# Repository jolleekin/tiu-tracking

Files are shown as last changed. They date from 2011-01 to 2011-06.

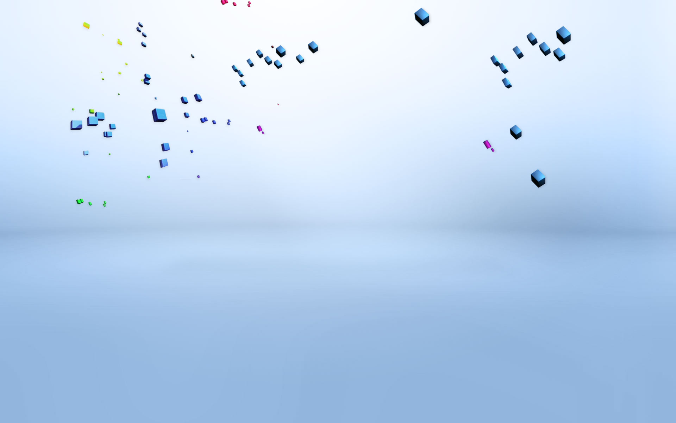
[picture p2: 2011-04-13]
Software/WebApp/images/bg_cubes.jpg

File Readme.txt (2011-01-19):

TIUTRACKING - RFM12's TxRx v.1 -------------------------------------------------------
Demo package for our capstone project -  TIU Tracking (PSU, Intel) - version 1.0
by Dung Dang Le - Email: zung.dang.le at gmail.com

This package demonstrates wireless communication on hobby frequency 
band (i.e 433MHz...) using RFM12B transceiver modules and ATMega328 uC.
Our purpose is testing these RFM12B module functions: transmit/receive/Analog-RSSI,
which could be considered applying for our project later.

There are two different approaches will be introduced:
    + polling, no checksum based on Benedikt's library
	+ interrupt with checksum based on RF12 arduino library by Jeelabs 
	
Notes: 
 - No collision avoidance is considered yet in this version
 - To get ARSSI output, you may have to manually solder on a wire to a resistor to 
   access this pad (see picture on schematic folder, location shown in red circle).
   (thanks to Stephen Eaton)
 - Schematic provided by Jeelabs, used for both transmiting receiving modules
 - Antennas required for best performance, Ideally at 433MHz ~ 17cm length
 - Yeah, I used arduino board to program the chips and monitor the serial outputs
 ------------------------------------------------------------------------------------

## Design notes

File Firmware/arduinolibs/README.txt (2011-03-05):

DDL: PUT THESE LIBRARIES IN ARDUINO LIBRARY FOLDER.

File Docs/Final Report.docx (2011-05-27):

# Abstract

TIU tracking system is a capstone project conducted by Portland State University students and sponsored by Intel Corp. The system will be used to track locations of Test Interface Units (TIUs) in the Intel Validation Lab.

In this paper, we propose a general architecture for the tracking system. The main goal of the architecture aims to achieve a low-cost, yet effective tracking system. The infrastructure of the tracking system is built upon RF transceivers which communicate wirelessly in a mesh network. The asset tags will be attached to tracked devices (TIUs). These asset tags will broadcast messages to detectors. Messages that contain received signal strength indication (RSSI) values will be routed though the mesh network to a server. The server will analyze the received data, calculate the locations, and store them in the database. A web application will then be able to access the database and display location information in an interactive 2D map.

The primary figures of merit that were used in the decision making process include accuracy, power consumption, size, and cost. The last administrative idiom this paper conveys is a road map which will guide our team to the final objective. The means by which this is accomplished is through a tentative schedule, timeline, a list of milestones and expected deliverables.

# 1 Introduction

Location aware computing has a bright future in the fields of personal navigation, personal security, prompt healthcare and entertainment. Furthermore, information on the physical location of mobile nodes can greatly help in urban search and rescue missions, as well as enable geographical routing in ad hoc multi-hop networks. The determination of physical location is sometimes referred to as location estimation, location identification, localization, and positioning or geolocation identification.

Chip manufacturers today face dramatic upheaval across the industry. Companies (such as Intel) need to find ways to remain profitable at a time when economic turbulence is curtailing consumer buying power. In the midst of these changes, plant managers must find a way to address the problem of improving processes while becoming more cost-effective.

As part of this effort, Intel wants to automate tracking of the Test Interface Units (TIU) at different locations of the Intel lab, with the intention of wirelessly locating a TIU’s physical position at all times. Given the size and complexity of Intel validation lab, locating Test Interface Units (TIU) can be a tedious task since the test equipments have to be broken down to identify the TIU it is using. Therefore, an effective TIU tracking system rises as an urgent need.

By tracking location of the TIU’s physical position in the lab, Intel can minimize downtime and decrease labor costs caused by the size and complexity of Intel validation lab. This solution enables:

- Increased equipment utilization
- Decreased loss and theft
- Reduced costs
- Faster production
- Avoid time wasted on manual searches and inventory checks.

This capstone project will be a prototype system that can wirelessly track the location of at least 10 TIUs in an indoor environment. The duration of the project will last 6 months.

# 2 Specification

## 2.1 System Overview

Figure 3-1 shows a network of detectors that are geometrically located in a grid array. The density of the grid array will primarily be a ratio of accuracy and cost. For the scope of this project, the reasonable number of detectors would be from five to seven. The location of the proxy must be within range of at least one detector.

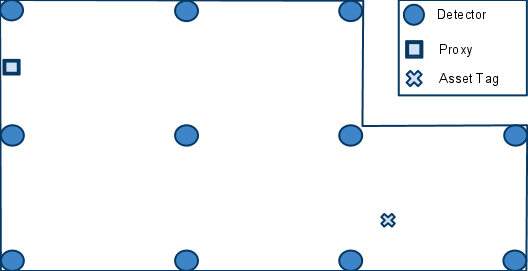
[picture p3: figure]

Figure 1: A hypothetical room with detectors positioned in a grid array. Also shown is an arbitrarily placed proxy.

There are two distinct networks which compose this system: the front-end network, which includes all the physical nodes, and the back-end network, which includes all the logical nodes (Figure 3-2). The proxy is the gateway between the two networks.

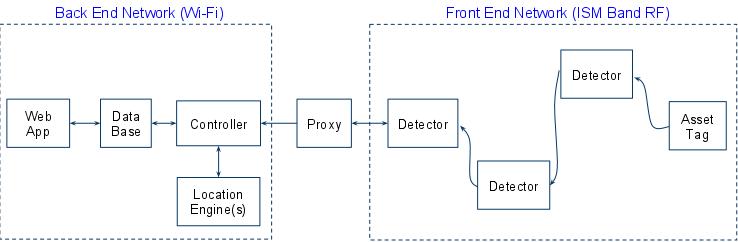
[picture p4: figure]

Figure 2: Front-end and back-end network topologies.

There are three important aspects to the communications that take place in the front-end network.

- Each asset tag will broadcast a message periodically. Neighboring detectors will detect the broadcast, and determine the RSSI of the broadcasting asset tag.
- When a detector determines the RSSI of a broadcasting asset tag, it must then transmit this data towards the proxy using a routing table. The routing table will be configured in such a way as to ensure the data moves in a direction that is physically towards the proxy.
- The locating application will periodically receive bursts of RSSI information from various detectors. Since it has no knowledge of how many detectors actually detected a broadcasting asset tag, it will wait a certain amount of time that assumes all the RSSI information from the various detectors has finished coming in.

Now we will further discuss some finer points of the second aspect. Figure 3-3 shows the paths taken as a result of an asset tag’s broadcasting. When an asset tag broadcasts, the nearest detectors are able to determine the corresponding RSSI values. The detectors that detected the asset tag broadcast are denoted by a connection with a green arrow. Each detector will have a routing table programmed into them. The routing table will contain information that steers the messages physically toward the proxy. In the example shown in Figure 3-3, the routes taken are in red. The blue dash paths are routes that exist but are not taken.

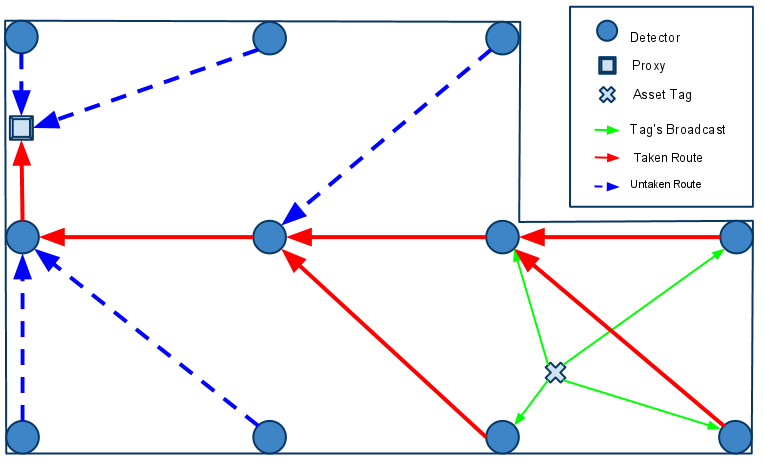
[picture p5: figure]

Figure 3: An example of the routing paths as a result of an asset tag’s broadcasting.

## 2.2 Software

### 2.2.1 Front-end Software

The front-end software consists of the firmware for the detectors, and the asset tags.

For a detector to determine the RSSI of an asset tag, the asset tag must broadcast a message. The message has six fields, as shown in Figure 3-4. The way the fields are used depends on the origin of the message. There are two possible origins of a message. The first type of origin is an asset tag. A message can be identified as coming from an asset tag by examining the DID, SID, and RSSI value fields. If all three fields contain the value zero, then the message originates from an asset tag. Otherwise, the message originates from a detector.

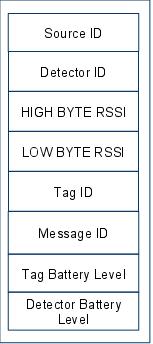
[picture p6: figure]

Figure 4: Message format.

When receiving a message whose DID is not zero, a detector will do four things:

1. Replace the DID of the message with a DID contained in its routing table
2. Replace the SID of the message with its own ID
3. Replace the RSSI value with that inferred from the reception of the asset tag broadcast
4. Rebroadcast the message

An example of this message passing sequence is show in Figure 5. (Need modified)

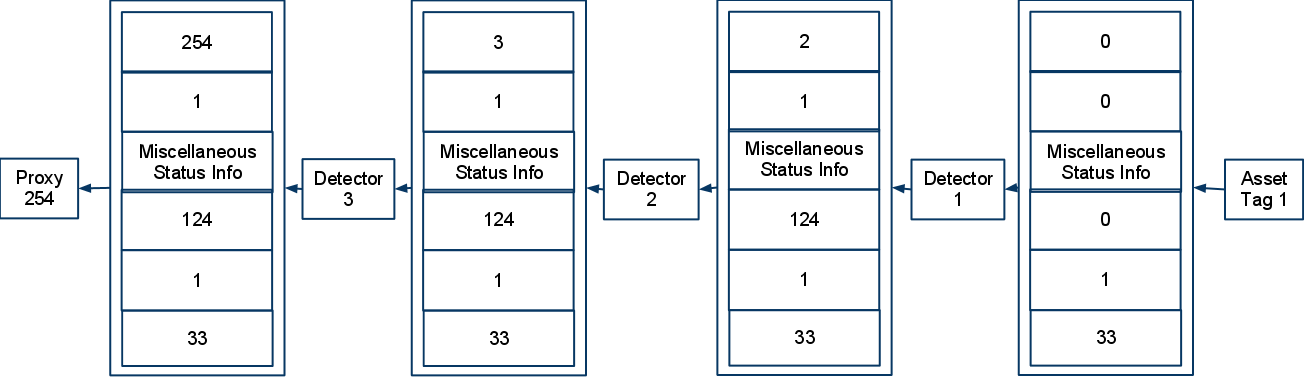
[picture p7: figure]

Figure 5: A example of a message originating from a asset tag, and being relayed to a proxy.

### 2.2.2 Back-end Software

The back-end network, composed exclusively of logical nodes, will rely on normal internet communication. This allows applications to leverage TCP/IP and many APIs that have been built upon it. Also, we gain the advantage of being able to have standard inter-nodal communication regardless of if they exist on the same computer or not. This increases the scalability of the system.

The back-end software system consists of four components:

- SQL Database
- Web Application
- Controller
- Location Engine

#### 2.2.2.1 SQL Database

The SQL database is a central component that provides a link among the web application, the controller, and the location engine. Specifically, the database stores the following data:

- Location update interval
- Geometry of the tracking area
- RSSI-distance model or RF fingerprinting
- Identifications and locations of the detectors
- Identifications, locations, and battery levels of the TIUs
- Mapping table between asset tags’ ID and TIUs’ ID

We agree on using SQL since it is a standard that is easy to use, secure and scalable.

#### 2.2.2.2 Web application

The web application provides an interface for users to access the location information in the database. Its functionalities are:

- Display the locations and battery levels of all tracked TIUs on an interactive 2D map
- Allow users to search for a TIU via its ID. In case the ID is not complete or unique, the application will highlight the locations of all matched TIUs
- Allow users to view location history of the TIUs
- Alert users when a TIU is brought out of bounds or when it runs out of battery

The web application consists of two components: the client side and the server side. The client side will be implemented using modern web technologies such as HTML5, JavaScript, CSS3, and AJAX. The server side could be built upon one of the two most popular web server applications, i.e. Microsoft IIS and Apache.

#### 2.2.2.3 Controller

The controller application is a GUI application that allows an administrator to manage the system. It allows the administrator to

- Modify the geometry of the tracking area
- Remap asset tags’ ID to TIUs’ ID
- Add or remove devices (detectors and asset tags)

The controller also receives RSSI data from the proxy, preprocesses them before feeding them into the location engine.

#### 2.2.2.4 Location Engine

The location engine receives RSSI values from the controller and uses those values to calculate the locations of the asset tags. The derived locations will then be stored in the database.
In case of using battery to power the asset tags, this application also receives battery level reports of the asset tags from the detectors and update the data in the database. This application should be written in a programming language that supports SQL database access and network communication.

The controller and the locating applications are discussed herein as two separate applications. However, they can definitely be combined into one single application.

## 2.3 Hardware

### 2.3.1 Tag

An asset tag consists of two major parts:

- Microcontroller: ATMega328P – 32 TQFP
- RF transceiver: RFM12B-S2 Wireless Transceiver Module

Table 1: Tag Specifications

Specification | Description
Microcontroller | ATMega328P – 32 TQFP
RF Transceiver | RFM12B-S2 Wireless Transceiver
Voltage regulator | XC6221
Power supply | 6V Battery (two 3-V coin cells in holder)
Program Interface | ISP 6-pin header
Operating Frequency Band | ISM 433 MHz
Power Indicator | No
RF Indicator | No
PCB size
Microcontroller module | 25.4mm x 25.4mm
RF Transceiver | 20.3mm x 25.4mm
Outline Dimension

Table 2: Electrical Characteristics

Specification | Min | Typ | Max | Unit
Power Supply | 3.3 | 6.0 | 6.0 | V
Transmit Current
Receive Current
Idle Current
Power-down Current
Power Dissipation
Operating Temperature | -25 | | +85 | ⁰C

The microcontroller controls the RF transceiver. The RF transceiver is responsible for communicating information to the system.

Figure 6: Board layout of the controller module on a tag

Figure 7: Board layout of the RF module on a tag

### 2.3.2 Detector

A detector consists of two major parts:

- Microcontroller: ATMega328P – 28 DIP
- RF transceiver: RFM12B-S2 Wireless Transceiver

Table 3: Detector Specifications

Specification | Description
Microcontroller | ATMega328P – 28 DIP
RF Transceiver | RFM12B-S2 Wireless Transceiver
Voltage regulator | MIC5205 150mA Low-Noise LDO Regulator
Power supply | 9V Battery
Program Interface | ISP 6-pin header
Operating Frequency Band | ISM 433 MHz
Power Indicator | Yes (regular red LED)
RF Indicator | Yes (green LED)
PCB size | 25.4mm x 88.9mm
Outline Dimension

Table 4: Electrical Characteristics

Specification | Min | Typ | Max | Unit
Power Supply | 3.3 | 9.0 | 16.0 | V
Transmit Current
Receive Current
Idle Current
Power-down Current
Power Dissipation
Operating Temperature | -25 | | +85 | ⁰C

Figure 8: Board layout of a detector

The microcontroller controls the RF transceiver. The RF transceiver is responsible for communicating information to the system.

### 2.3.3 Proxy

The proxy consists of three major parts:

- Microcontroller unit
- RF transceiver unit: RFM12B-S2 Wireless Transceiver Module
- Wi-Fi transceiver: WiFly GSX Module

Table 5: Proxy Specifications

Specification | Description
Microcontroller | ATMega328P – 28 DIP
RF Transceiver | RFM12B-S2 Wireless Transceiver
Voltage regulator | LM317
Power supply | 6V Battery
Program Interface | USB
Operating Frequency Band
RF Transceiver | ISM 433 MHz
Wi-Fi Transceiver | 2.4 GHz Standard
Power Indicator | Yes
Transmission Indicator | Yes
Outline Dimension | Prototype on bread board

Table 6: Electrical Characteristics

Specification | Min | Typ | Max | Unit
Power Supply | 3.3 | 6V | 6V | V
Transmit Current
Receive Current
Idle Current
Power-down Current
Power Dissipation
Operating Temperature | -25 | | +85 | ⁰C

The microcontroller is responsible for relay data between the two transceivers.

### 2.3.4 Parts Selection

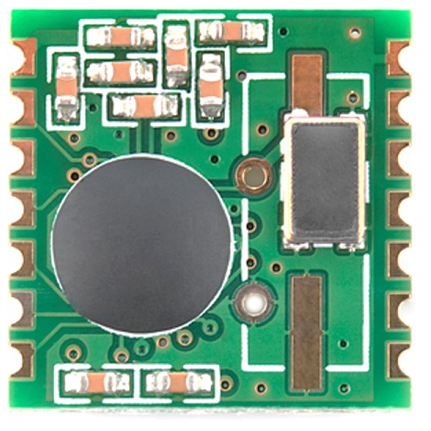
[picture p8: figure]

Figure 9: RFM12B-S2 Wireless Transceiver Module

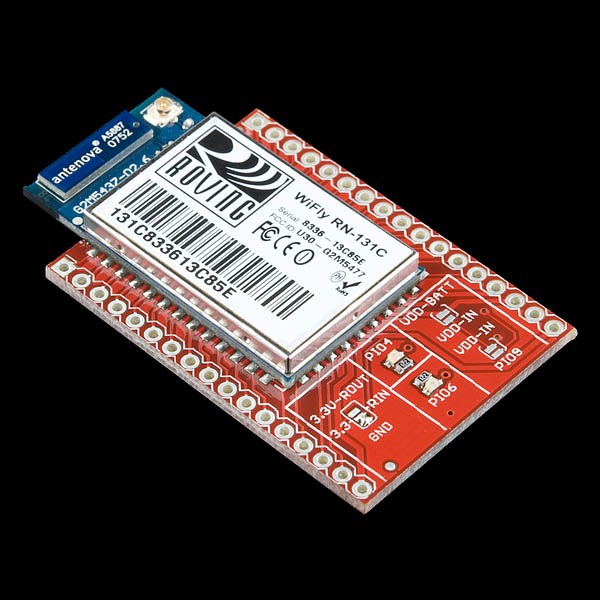
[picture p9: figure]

Figure 10: WiFly GSX Breakout

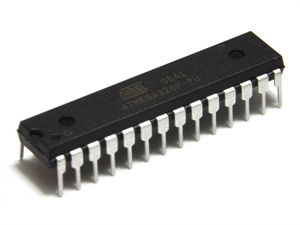
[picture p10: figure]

Figure 11: ATMega328P – 28 DIP Pinout

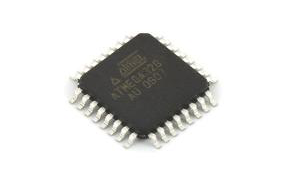
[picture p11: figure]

Figure 12: ATMega32P – 32 TQFP Pinout

Refer to datasheets provided by manufacturers for more information (See Useful Links section in Appendices).

# 3 Test Plan

## 3.1 Unit Tests

## 3.2 Hardware

### 3.2.1 Power supply unit

### 3.2.2 Tag

### 3.2.3 Detector

### 3.2.4 Proxy

## 3.3 Software

### 3.3.1 Controller

### 3.3.2 Web App

### 3.3.3 Database

## 3.4 System Tests

### 3.4.1 Test case 1:

1 Tag, 1 Detector, Serial

### 3.4.2 Test Case 2:

1 Tag, 1 Detector, Proxy

### 3.4.3 Test Case 3:

1 Tag, Multiple Detectors

### 3.4.4 Test Case 4:

Multiple Tags, Multiple Detectors, Proxy, Database

## 3.5 Acceptance Tests

### 3.5.1 Test case 1:

10 Tags, 8 Detectors, Proxy, Controller, Web App

Accuracy Requirement Met?

Power Requirement Met?

Update Interval Requirement Met?

## 3.6 Final Results

### 3.6.1 Device dimensions

### 3.6.2 Power consumption

### 3.6.3 Accuracy

# 4 Conclusions

## 4.1 What we learned

## 4.2 Good Decisions

## 4.3 Bad Decisions

## 4.4 Meeting our Expectations

## 4.5 Meeting our Sponsors Expectations

## 4.6 Group Dynamics

# 5 Appendices

## 5.1 Installation

### 5.1.1 Detector Deployment

### 5.1.2 Tag Deployment

### 5.1.3 Controller Setup

### 5.1.4 Proxy Setup

## 5.2 Maintenance

### 5.2.1 Replacing Batteries

## 5.3 User Guide

### 5.3.1 Web-based application

### 5.3.2 Controller application

## 5.4 Useful Links

# 6 References

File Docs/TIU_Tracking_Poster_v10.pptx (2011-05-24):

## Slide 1

TIU Tracking System

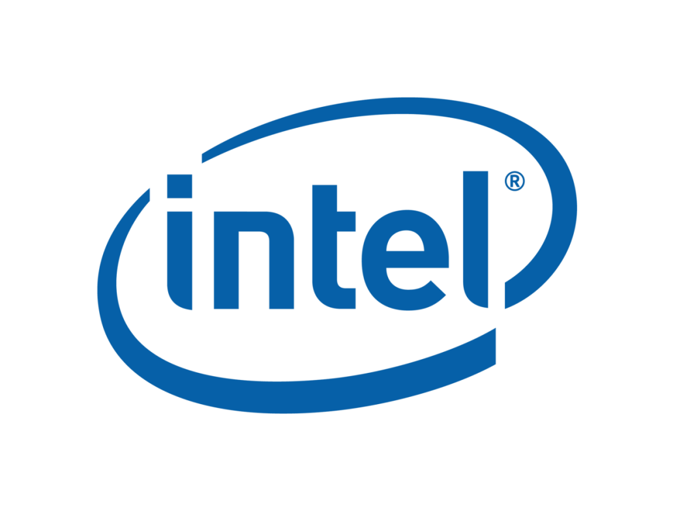
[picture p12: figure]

Capstone 2011
Sponsored by Intel
Advisor: Prof. Robert Daasch

Team Members:
Daniel Ferguson – Dung Le
Lynh Pham – Man Hoang – Tri Truong

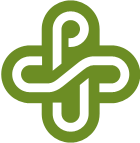
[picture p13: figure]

Introduction

Intel's large and complex validation labs contain many Test Interface Units (TIUs) used in validating hardware. A TIU is a custom PCB that provides test points that a testing machine can probe. Since the hardware to be tested is varied, there exists a variety of different TIU's, and as such, finding a particular TIU is useful because, previously, the testing machine had to be broken down to identify the TIU it was using.

Approach

The system uses an RF transceiver mesh network to track mobile tags indoors. The system determines a tag’s current location by matching the RF signal strength pattern of a tag’s periodic broadcast with pre-collected patterns stored in a database.
Radio Received Signal Strength Indication (RSSI) is a measurement of the power received by an antenna. Signal strength based location method has several advantages over other methods such as GPS, IR, and Acoustics as it is easy to implement and does not require line of sight. Also, low cost RF transceivers are readily available.
For scalability, a mesh network of detectors relay all data to a centralized controller where locations of the tags are calculated and saved in a database. An easy to use web application provides visualization of tag locations, as well as other configuration details.

Design

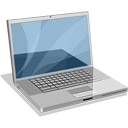
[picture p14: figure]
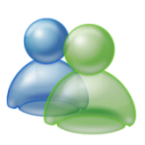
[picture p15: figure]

Users

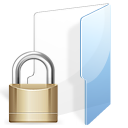
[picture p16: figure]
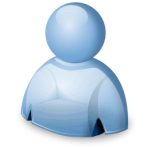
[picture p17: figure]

Admin

Back-end

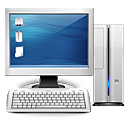
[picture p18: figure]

Web App

Controller

Front-end

Wi-Fi

Database

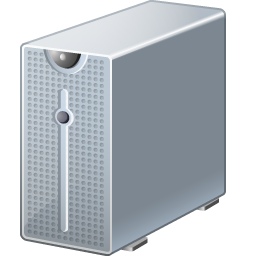
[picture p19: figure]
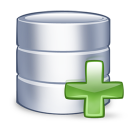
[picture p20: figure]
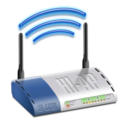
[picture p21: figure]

Proxy

Detector

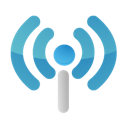
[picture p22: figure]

Tag

Products

Asset Tag
- Size: 1”x1”x1”
- ATMega328p MCU
- RF12B transceiver at 434MHz
- 20mm coin cell battery
- Battery life: at least 1 months
- Cost : $25

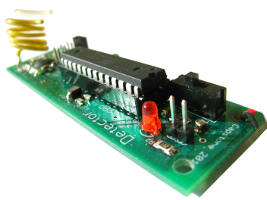
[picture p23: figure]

Detector
- Size: 3.5”x1”
- ATMega328p MCU
- RF12B transceiver at 434MHz
- 9V battery/adapter
- Cost: $30

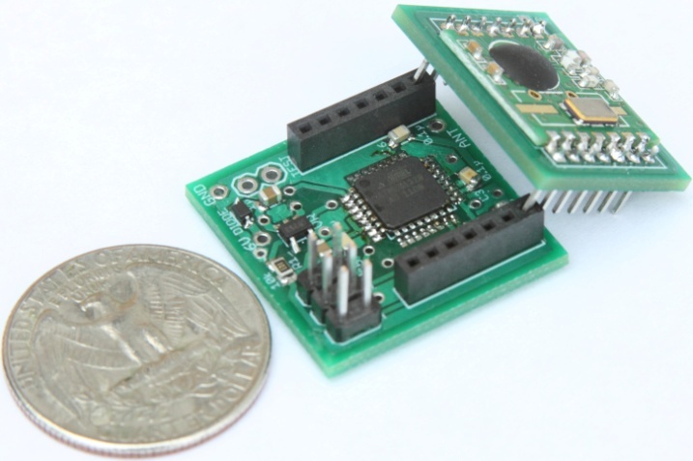
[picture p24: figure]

Controller
- Receives RSSI and battery data from the mesh network
- Executes the locating algorithm
- Communicates with the Database
Fingerprint Algorithm
- A pattern matching algorithm based on Euclidean distance
- Employs heuristics and input/output filters to further enhance the accuracy and reliability of the locating process
where
- d = Euclidean distance
- N = Number of detectors
- RSSIli = RSSI value from detector i in locating phase
- RSSIci = RSSI value from detector i in calibrating phase
Web Application
- Primary user interface with an interactive 2D map
- Search TIUs and detectors via ID
- Display locations and battery levels of all tags and detectors
- Configure tags and detectors
- Configure the tracking area

Tags
- Attached to TIUs
- Periodically broadcast
- When not broadcasting, in a low power state
Detectors
- Listen to messages from tags and determine the RSSI values
- Forward the messages to the proxy via a controlled flooding mechanism
- Implements collision avoidance using time division
Wi-Fi Proxy
- Relays data from the mesh network to the controller
SQL Database
- Stores locations and battery levels of all tags and detectors
- Stores user accounts

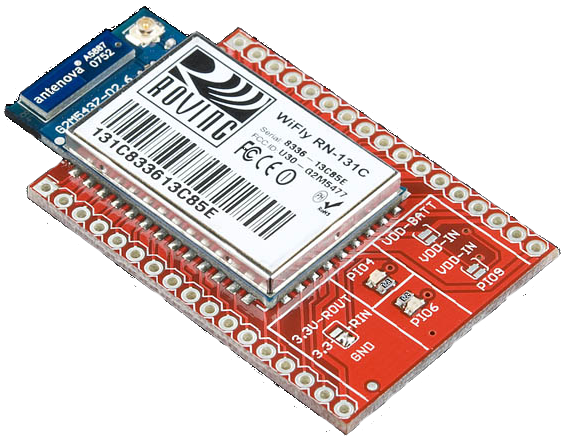
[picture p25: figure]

Proxy
- ATMega328p MCU
- RF12B transceiver at 434MHz
- WiFly 802.11b/g transceiver
- 9V battery/adapter
- Cost: $80

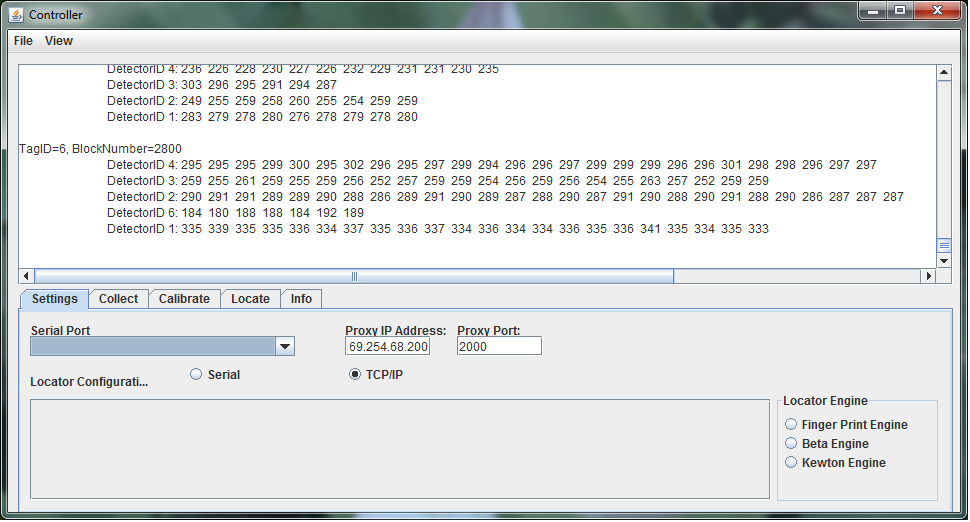
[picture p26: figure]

Experiments


Conclusions

The system has been able to meet three important requirements: small size, low cost, and battery life exceeding one month. As for accuracy, the average value is roughly 2m. The result is much better when the tags are close to the calibration points.
Further work to be done includes
- Refine the testability of the system
- Analyze antenna radiation pattern
- Improve the robustness of the location algorithm

Department of Electrical and Computer Engineering


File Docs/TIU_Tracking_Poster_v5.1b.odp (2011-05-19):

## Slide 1

Requirements

- Asset tag’s size: 1” x 1” x 1”
- Low power consumption
- Accurate
- Web application as user interface
- 2D map display
- Scalable tracking area
- Low cost solution

Introduction

This system uses an RF transceiver network to track mobile assets indoors, where more obvious solutions, such as GPS, are unable to function. A web app is the primary user interface, and is used to query the location of an asset.

Tags, which are placed onto Testing Interface Units(TIUs), periodically broadcast a signal which are picked up by detectors that are placed in various fixed locations within the tracking area. The detectors determine the signal strength of the tags, form a message and relay it, via a mesh network forwarding protocol, until the message reaches the proxy. The proxy then retransmits the message via wifi to the controller. The controller gives the signal strength data to a locating algorithm which calculates its approximate location via statistical analysis. The results are then placed into a database where the web app retrieves the results and displays them on an interactive 2D map.

Design


Proxy


Controller

Detector


Users


Admin

Web App


TIU Tracking System


Capstone 2011

Sponsored by Intel

Advisor: Prof. Robert Daasch

Team Members:

Daniel Ferguson – Dung Le

Lynh Pham – Man Hoang – Tri Truong

Products


Asset Tag

- Size: 1”x1”x1”
- Use ATMega328p MCU
- Use 20mm coin cell battery
- Battery life: more than 3 months
- Use RF12B transceiver at 434MHz

Detector

- Size: 3.5”x1”
- Use ATMega328p MCU
- Use 9V battery/adapter
- Use RF12B transceiver at 434MHz


Features

RF Mesh Network

- Composed of small, inexpensive hardware.
- Relay messages to proxy via a controlled flooding mechanism.
- Collision avoidance using time division
- Tags broadcast periodically
- Detectors pick up broadcast, determine RSSI, and send results.
- Detectors also act as relays.

Wi-Fi Proxy

- RFM12 receives data from mesh network
- Wifi module sends data to the controller.

Fingerprint Algorithm

- A progressively constrained, nearest neighbor algorithm, using euclidean distance as the matching metric. Also, several heuristics are employed that further enhance the accuracy and reliability of the locating process.

Controller

- Primary link between the mesh network and the back end infrastructure.
- Communicates with mesh network
- Executes the locating algorithm
- Communicates with the Database.

Approach

By collecting RF signatures and storing them in a database. The RF signature created by a tag's broadcast can be compared to those stored, and the closest match roughly identifies the location of the tag.

Data originates in the mesh network, and is relayed to controller software that feeds it to a locating algorithm. The locating algorithm calculates the location, gives the results back to the controller, and the controller then places the results into the database.

The locating algorithms implement a standardized interface which facilitates easy integration with the system, and supports the addition of different locating algorithms.

Test Results


Web Application

- Primary user interface.
- Interactive 2D map
- Search TIU and detector via ID
- Show battery level of all elements in the mesh network.
- Configure Detector placement
- Configure geometry of tracking area

SQL Database

- Tag locations
- Battery levels of all transceiver devices

Conclusions

The accuracy of the tracking system needs to be enhanced by considering antenna design and advanced locating algorithm. Noise filter can be implemented on both hardware and software to achieve desired performance.

Database

Department of Electrical and Computer Engineering


Tag


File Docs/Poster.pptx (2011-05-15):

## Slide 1

TIU Tracking System


Capstone 2011

Introduction

This system uses an RF transceiver network to track mobile assets indoors, where more obvious solutions, such as GPS, are unable to function. The system determines an asset’s current location by matching the RF fingerprint of its periodic broadcasts with previously collected fingerprints stored in a database

Requirements
- Asset tag’s size: 1” x 1” x 1”
- Low power consumption
- Accurate
- Web application as user
- interface
- 2D map display
- Scalable tracking area
- Low cost solution

Team
Sponsor: Intel
Advisor: Prof. Robert Daasch
Members: Dung Le
Tri Truong
Lynh Pham
Man Hoang
Daniel Ferguson

Design

Infrastructure
RF Network
Location Algorithm
Fingerprint
User Interface
Web App
Management
Wi-Fi Proxy
Server Computer
Voting Method
Controller
Web App

Results

Conclusions
The tracking system consists of two primary parts: hardware and software. The hardware infrastructure is built upon RF technology. The number of detectors will be scaled in order to achieve the desired accuracy and efficiency.

Asset Tag
- Size: 1”x1”x1”
- Use RF12B transceiver at 434MHz
- Use MCU ATMega328p
- Use coin cell 20mm battery
- Battery life: more than 1 month


Proxy
- Use WiFly 802.11b/g at 2.4GHz
- Use RF12B transceiver at 434MHz
- Use MCU ATMega328p
- Use 9V battery/adaptor

Controller
- ghghghghdgfh
- fggfhgh

Web Application
- User and Admin interface
- Interactive 2D map
- Search TIU and detector via ID
- Show battery level
- Add and remove tag/detector
- Change geometry of tracking area

SQL Database
- RSSI-distance model or RF fingerprinting
- Location update interval
- Geometry of the tracking area
- Identifications, locations, and battery levels of the TIUs


Detector
- Size: 3.5”x1”
- Use RF12B transceiver at
434MHz
- Use MCU ATMega328p
- Use 9V battery/adapter


Admin

Back-end


Internet

Front-end


Users


Detector


Tag

Disadvantages

- Noise sensitive
- Calibration required

Detector


Controller


Proxy


Battery Life

- Capacity of lithium coin cell: 240mAh
- Transmission time: 3ms every 1 seconds
- Active current: 30mA (RF transceiver + MCU)
- Sleep current: 0.0425mA


Accuracy

- Testing ………

Detector


Advantages

- Low cost
- Small size
- Easy scalability
- Low power consumption

Department of Electrical and Computer Engineering

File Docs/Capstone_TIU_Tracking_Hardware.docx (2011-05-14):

# 1 Hardware

The infrastructure of the tracking system consists of detectors, asset tags, proxies and a server, as shown in Figure below


## 1.1 Detectors

A detector consists of two major parts: a microcontroller, and a RF transceiver. The microcontroller controls the RF transceiver. The RF transceiver is responsible for communicating information to the system.

### 1.1.1 Functionality


Figure 1: Detector functionality

Module | Detectors
Inputs | - Power supply: 3.3V DC - Messages from asset tags and other detectors
Outputs | - Messages from asset tags and other detectors
Functionality | A detector consists of two major parts: a microcontroller, and a RF transceiver. The microcontroller controls the RF transceiver. The RF transceiver is responsible for communicating information to the system.

### 1.1.2 What is on the board

- A power switch on/off
- A 3.3V power regulator which accepts up to 16V as external power source.
- An ATMega328p MCU by Atmel with 8MHz
- A 6pins SPI connector for programming.
- A RFM12B wireless RF module for 434MHz ISM band by Hope RF.
- A LED with jumper (on/off) for checking power.
- A LED with jumper (on/off) for checking signal transmission.

### 1.1.3 Advantage

- By including a 3.3V regulator, the detector can be powered a DC power adapter, or various types of 3.6 … 16V batteries.
- The RFM12B module is a low cost option with sufficient power and range to provide reliable communication around the lab - a basic packet protocol can be implemented in just 2..3 Kb of C code.
- Had 2 LEDs for debugging power and signal transmission.
- Small size 1” x 3.5”.
- There are many possible microcontrollers we could use to implement a solution. The ATmega 328p is a good choice because they are the Arduino technology platform.
- FR12B transceiver is a good choice because of low price, good support and low power consumption.

### 1.1.4 Schematic


## 1.2 Board layout


## 1.3 Real Board


### 1.3.1 Port/Pin Mapping

#### 1.3.1.1 ATMage328p – 28pins


Pin | Name | Description
1 | PC6 | RESET/PCINT14
2 | PD0 | PCINT16/RXD
3 | PD1 | PCINT17/TXD
4 | PD2 | PCINT18/INT0
5 | PD3 | PCINT19/OC2B/INT1
6 | PD4 | PCINT20/XCK/T0
7 | VCC | VCC
8 | GND | GROUND
9 | PB6 | PCINT6/XTAL1/TOSC1
10 | PB7 | PCINT7/XTAL2/TOSC2
11 | PD5 | PCINT21/OC0B/T1
12 | PD6 | PCINT22/OC0A/AIN0
13 | PD7 | PCINT23/AIN1
14 | PB0 | PCINT0/CLKO/ICP1
15 | PB1 | OC1A/PCINT1
16 | PB2 | SS/OC1B/PCINT2
17 | PB3 | MOSI/OC2A/PCINT3
18 | PB4 | MISO/PCINT4
19 | PB5 | SCK/PCINT5
20 | AVCC | AVCC
21 | AREF | AREF
23 | GND | GROUND
23 | PC0 | ADC0/PCINT8
24 | PC1 | ADC1/PCINT9
25 | PC2 | ADC2/PCINT10
26 | PC3 | ADC3/PCINT11
27 | PC4 | ADC4/SDA/PCINT12
28 | PC5 | ADC5/SCL/PCINT13

#### 1.3.1.2 SPI connector


Pin | Name | Description
1 | MISO | master in / slave out
2 | +5V | Regulated +5V
3 | SCK | SPI clock
4 | MOSI | master out / slave in
5 | RESET | Reset
6 | GND | ground

#### 1.3.1.3 RFM12B


Pin | Name | Description
1 | SDO | Serial data output
2 | nIRQ | Interrupts request output
3 | FSK/DATA/nFFS | Transmit FSK data input/Received data output/FIFO select
4 | DCLK/CFIL/FFIT | Clock output/Extrenal filter capacitor/FIFO interrupts
5 | CLK | Clock output for external microcontroller
6 | nRES | Reset output
7 | GND | Ground
8 | ANT | Antenna
9 | VDD | VCC
10 | GND | Ground
11 | nINT/VDI | Interrupt input
12 | SDI | SPI data input
13 | SCK | SPI clock input
14 | nSEL | Chip select

### 1.3.2 Part list

Part | Value | Details
ATMega328 | Atmel's ATMega328 | Atmel's ATMega328 8-Bit Processor in 28 pin DIP
RFN12B | RFM12B-S2 | RFM12B-S2 Wireless Transceiver
Socket IC | Socket for ATMega328p | Socket IC open frame 28Pos 0.3”
SPI | SPI 6 pins connector | 6 POS connector header
PWR_SW | Power switch | SPDT Mini Power Switch
VR | Voltage regulator 3.3V | IC VREG LDO 3.3V
DIODE | Diode | DIODE SBR 1A 30V SOD-323
C1, C1 | 1uF | CAP CERM 1UF 25V Y5V 0805
C3, C4, C5, C6 | 0.4uF | CAP CERM .10UF 50V 5% 0805 SMD
L1 | 10uH | INDUCTOR 10UH 10% SA TYPE SMD
R1 | 10K | RES 10K OHM 1/4W 5% 0805 SMD
PWR_LED | Power LED 3mm | Power LED 3mm
RF_LED | LED 3mm | LED for signal transmission
JP_RF_LED | 2 pins male header | 2 pins male header
JP_PWR_LED | 2 pins male header | 2 pins male header

## 1.4 Asset Tags

An asset tag consists of two major parts: a microcontroller, and a RF transceiver. The microcontroller controls the RF transceiver. The RF transceiver is responsible for communicating information to the system.

### 1.4.1 Functionality


Figure 2: Asset tag functionality

Module | Asset Tags
Inputs | Power supply: 3.3V DC
Outputs | Messages containing tag’s ID
Functionality | An asset tag consists of two major parts: a microcontroller, and a RF transceiver. The microcontroller controls the RF transceiver. The RF transceiver is responsible for communicating information to the system.

### 1.4.2 What is on the board

- A power switch on/off
- A 3.3V power regulator which accepts 2.2V to 6V as external power source.
- An ATMega328p MCU by Atmel with 8MHz
- A 6pins SPI connector for programming.
- A RFM12B wireless RF module for 434MHz ISM band by Hope RF.
- A jumper which connect to DP3 pin of ATMega328p for debug/mode.
- 2x7pins headers female for connecting with RFM12B breakout board.

### 1.4.3 Advantage

- Designed from the ground up to support very low-power use with batteries.
- The RFM12B module is a low cost option with sufficient power and range to provide reliable communication around the lab - a basic packet protocol can be implemented in just 2..3 Kb of C code.
- Very small size 1” x 1”
- Very low power consumption
- There are many possible microcontrollers we could use to implement a solution. The ATmega 328p surface mount packet is a good choice because they are the Arduino technology platform and very small size.
- FR12B transceiver is a good choice because of low price, good support and low power consumption

### 1.4.4 Battery life

- Capacity of coin cell: 240mAh
- Transmission time: 3ms every 1 seconds
- Active current: 30mA (RF transceiver + MCU)
- Sleep current: 0.0425mA

Then, the approximate battery life is

Battery Life=(240mAh)/(30.0425mA×(3ms)/(1s))=2662.89hr≈110.95days

### 1.4.5 Schematic


### 1.4.6 Board Layout


### 1.4.7 Real Board


### 1.4.8 Port/Pin Mapping

#### 1.4.8.1 ATMage328p – 32pins


Pin | Name | Description
1 | PD3 | PCINT19/OC2B/INT1
2 | PD4 | PCINT20/XCK/T0
3 | GND | GROUND
4 | VCC | VCC
5 | GND | GROUND
6 | VCC | VCC
7 | PB6 | PCINT6/XTAL1/TOSC1
8 | PB7 | PCINT7/XTAL2/TOSC2
9 | PD5 | PCINT21/OC0B/T1
10 | PD6 | PCINT22/OC0A/AIN0
11 | PD7 | PCINT23/AIN1
12 | PB0 | PCINT0/CLKO/ICP1
13 | PB1 | OC1A/PCINT1
14 | PB2 | SS/OC1B/PCINT2
15 | PB4 | MOSI/OC2A/PCINT3
16 | PB4 | MISO/PCINT4
17 | PB5 | SCK/PCINT5
18 | AVCC | AVCC
19 | ADC6 | ADC6
20 | AREF | AREF
21 | GND | GROUND
22 | ADC7 | ADC7
23 | PC0 | ADC0/PCINT8
24 | PC1 | ADC1/PCINT9
25 | PC2 | ADC2/PCINT10
26 | PC3 | ADC3/PCINT11
27 | PC4 | ADC4/SDA/PCINT12
28 | PC5 | ADC5/SCL/PCINT13
29 | PC6 | RESET/PCINT14
30 | PD0 | PCINT16/RXD
31 | PD1 | PCINT17/TXD
32 | PD2 | PCINT18/INT0

### 1.4.9 Part list

Part | Value | Details
ATMega328 | IC MCU AVR 32K FLASH 32TQFP | IC MCU AVR 32K FLASH 32TQFP
SPI | SPI 6 pins connector | 6 POS connector header
VR | Voltage regulator 3.3V | IC VREG LDO 3.3V
DIODE | Diode | DIODE SBR 1A 30V SOD-323
C1, C1 | 1uF | CAP CERM 1UF 25V Y5V 0805
C3, C4, C5, C6 | 0.4uF | CAP CERM .10UF 50V 5% 0805 SMD
R1 | 10K | RES 10K OHM 1/4W 5% 0805 SMD
LEFT | 2mm 7-pin Socket | 2mm 7-pin Socket
RIGHT | 2mm 7-pin Socket | 2mm 7-pin Socket
TEST | 2-pins header | 2-pins header
Battery | Coin Cell battery 20mm 240mAh | Coin Cell battery 20mm 240mAh

## 1.5 RFM12B Breakout Board

### 1.5.1 What is on the board

- A RFM12B wireless RF module for 434MHz ISM band by Hope RF.
- An antenna.

### 1.5.2 Advantage

- The breakout board for the RFM12B which gives you access to the pins.
- Easy to solder. And implement.
- Had an antenna on it.
- Very small size 0.8” x 0.9”

### 1.5.3 Schematic


### 1.5.4 Board Layout


### 1.5.5 Real Board


### 1.5.6 Part List

Part | Value | Details
RFN12B | RFM12B-S2 | RFM12B-S2 Wireless Transceiver
LEFT | 2mm 7-pin male header | 2mm 7-pin male header
RIGHT | 2mm 7-pin male header | 2mm 7-pin male header

Portland State University Capstone 2011 6

Portland State University Capstone 2011 1

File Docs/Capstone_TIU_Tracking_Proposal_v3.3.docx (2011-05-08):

Portland State University

Electrical and Computer Engineering Department

11

Capstone 2011

TIU Tracking Project Proposal

Sponsor: Intel

Advisor: Prof. Robert Daasch

Members: Dung Le

Tri Truong

Lynh Pham

Man Hoang

Daniel Ferguson

Version History

Version | Implemented By | Revision Date | Approved By | Approval Date | Reason
1.0 | Lynh Pham | 1/22/2011 | Prof. Daasch | 01/25/2011 | Proposal outline
2.0 | Dung Le Tri Truong Lynh Pham Man Hoang Daniel Ferguson | 2/06/2011 | | | Draft Proposal
3.0 | Dung Le Tri Truong Lynh Pham Man Hoang Daniel Ferguson | 2/15/2011 | | | Proposal
3.2 | Dung Le Tri Truong Lynh Pham Man Hoang Daniel Ferguson | 2/17/2011 | Prof. Daasch | 02/17/2011 | Modify as recommended by Prof. Daasch
3.3 | Man Hoang Daniel Ferguson | 2/19/2011 | | | Project cost rework

Abstract

TIU tracking system is a capstone project conducted by Portland State University students and sponsored by Intel Corp. The system will be used to track locations of Test Interface Units (TIUs) in the Intel Validation Lab.

In this paper, we propose a general architecture for the tracking system. The main goal of the architecture aims to achieve a low-cost, yet effective tracking system. The infrastructure of the tracking system is built upon RF transceivers which communicate wirelessly in a mesh network. The asset tags will be attached to tracked devices (TIUs). These asset tags will broadcast messages to detectors. Messages that contain received signal strength indication (RSSI) values will be routed though the mesh network to a server. The server will analyze the received data, calculate the locations, and store them in the database. A web application will then be able to access the database and display location information in an interactive 2D map.

The primary figures of merit that were used in the decision making process include accuracy, power consumption, size, and cost. The last administrative idiom this paper conveys is a road map which will guide our team to the final objective. The means by which this is accomplished is through a tentative schedule, timeline, a list of milestones and expected deliverables.

# 1 Introduction

Location aware computing has a bright future in the fields of personal navigation, personal security, prompt healthcare and entertainment. Furthermore, information on the physical location of asset tags can greatly help in urban search and rescue missions, as well as enable geographical routing in ad hoc multi-hop networks. The determination of physical location is sometimes referred to as location estimation, location identification, localization, positioning or geolocation identification.

Given the size and complexity of Intel validation lab, locating Test Interface Units (TIU) can be a tedious task as test equipment has to be broken down to identify the TIU it is using.

Chip manufacturers today face dramatic upheaval across the industry. Companies (such as Intel) need to find ways to remain profitable at a time when economic turbulence is curtailing consumer buying power. In the midst of these changes, plant managers must find a way to address the problem of improving processes while becoming more cost-effective. As part of this effort, Intel wants to automate tracking of the TIUs at different locations of the Intel lab, with the intention of wirelessly locating a TIU’s physical position at all times.

By tracking the location of the TIUs in the lab, Intel can minimize downtime and decrease labor costs caused by the size and complexity of Intel validation lab. This solution enables:

- Increased equipment utilization
- Decreased loss and theft
- Reduced costs
- Faster production
- Avoid time wasted on manual searches and inventory checks.

This proposal is organized as follows. In the next section, we present the project scope. In section 2, we present functional specification. In section 3, we present design proposal. In section 4, 5, 6, 7, 8, we present work breakdown structure, road map, task schedule, milestones and deliverables. In section 9, we present system requirements including hardware and software. In section 10, we present the project cost. Conclusions and appendices are presented in section 11 and 12.

This capstone project will be a prototype system that can wirelessly track the location of at least 10 TIUs in an indoor environment. The duration of the project will last 6 months.

# 1 Functional Specification

## 1.1 Functional Requirements

The key functionalities of the system are as follows:

- The primary user interface will be a web application
- Locations of TIUs will be displayed on an interactive 2D map within the user interface
- The user interface will show when an asset tag has low battery or when it is out of bounds

## 1.2 Non-Functional Requirements

- The system will be able to track any TIU within a 10,000 sq ft area
- A tester in Intel lab occupies roughly 25 sq feet and the system will be able to locate the TIUs with an accuracy of 5 feet
- The locations of tracked TIUs will be updated within 10 minute intervals
- The asset tags must fit within a 1” x 1” x 1” dimension
- The asset tags will be permanently attached to the TIUs during operation
- The asset tags must use their own source of power. If the power source is a battery, then life must exceed one month
- The system will provide a user interface for adding and removing devices
- The system will provide a user interface to configure the geometry of the tracking area
- The locations in the database will be retained for 2 years
- The system will be able to operate properly in temperature range from -25°C to 85°C
- Parts and components will be available for manufacturing and maintaining
- All documentations regarding design, setup, use, and maintenance will be provided
- The system will not infringe upon existing patents, copyrights and trademarks and will comply with FCC rules and regulations

# 2 Design Proposal

## 2.1 Topology

Figure 3-1 shows a network of detectors that are geometrically located in a grid array. The density of the grid array will primarily be a ratio of accuracy and cost. For the scope of this project, the reasonable number of detectors would be from five to seven. The location of the proxy must be within range of at least one detector.


Figure 3-1: A hypothetical room with detectors positioned in a grid array. Also shown is an arbitrarily placed proxy.

There are two distinct networks which compose this system: the front-end network, which includes all the physical nodes, and the back-end network, which includes all the logical nodes (Figure 3-2). The proxy is the gateway between the two networks.


Figure 3-2: Front-end and back-end network topologies.

There are three important aspects to the communications that take place in the front-end network.

- Each asset tag will broadcast a message periodically. Neighboring detectors will detect the broadcast, and determine the RSSI of the broadcasting asset tag.
- When a detector determines the RSSI of a broadcasting asset tag, it must then transmit this data towards the proxy using a routing table. The routing table will be configured in such a way as to ensure the data moves in a direction that is physically towards the proxy.
- The locationing application will periodically receive bursts of RSSI information from various detectors. Since it has no knowledge of how many detectors actually detected a broadcasting asset tag, it will wait a certain amount of time that assumes all the RSSI information from the various detectors has finished coming in.

Now we will further discuss some finer points of the second aspect. Figure 3-3 shows the paths taken as a result of an asset tag’s broadcasting. When an asset tag broadcasts, the nearest detectors are able to determine the corresponding RSSI values. The detectors that detected the asset tag broadcast are denoted by a connection with a green arrow. Each detector will have a routing table programmed into them. The routing table will contain information that steers the messages physically toward the proxy. In the example shown in Figure 3-3, the routes taken are in red. The blue dash paths are routes that exist but are not taken.


Figure 3-3: An example of the routing paths as a result of an asset tag’s broadcasting.

## 2.2 Software

### 2.2.1 Front-end Software

The front-end software consists of the firmware for the detectors, and the asset tags.

For a detector to determine the RSSI of an asset tag, the asset tag must broadcast a message. The message has six fields, as shown in Figure 3-4. The way the fields are used depends on the origin of the message. There are two possible origins of a message. The first type of origin is an asset tag. A message can be identified as coming from an asset tag by examining the DID, SID, and RSSI value fields. If all three fields contain the value zero, then the message originates from an asset tag. Otherwise, the message originates from a detector.


Figure 3-4: Message format.

When receiving a message whose DID is not zero, a detector will do four things:

1. Replace the DID of the message with a DID contained in its routing table
2. Replace the SID of the message with its own ID
3. Replace the RSSI value with that inferred from the reception of the asset tag broadcast
4. Rebroadcast the message

An example of this message passing sequence is show in Figure 3-5.


Figure 3-5: A example of a message originating from a asset tag, and being relayed to a proxy.

### 2.2.2 Back-end Software

The back-end network, composed exclusively of logical nodes, will rely on normal internet communication. This allows applications to leverage TCP/IP and many APIs that have been built upon it. Also, we gain the advantage of being able to have standard inter-nodal communication regardless of if they exist on the same computer or not. This increases the scalability of the system.

The back-end software system consists of four components:

- SQL Database
- Web Application
- Controller
- Location Engine

#### 2.2.2.1 SQL Database

The SQL database is a central component that provides a link among the web application, the controller, and the location engine. Specifically, the database stores the following data:

- Location update interval
- Geometry of the tracking area
- RSSI-distance model or RF fingerprinting
- Identifications and locations of the detectors
- Identifications, locations, and battery levels of the TIUs
- Mapping table between asset tags’ ID and TIUs’ ID

We agree on using SQL since it is a standard that is easy to use, secure and scalable.

#### 2.2.2.2 Web Application

The web application provides an interface for users to access the location information in the database. Its functionalities are:

- Display the locations and battery levels of all tracked TIUs on an interactive 2D map
- Allow users to search for a TIU via its ID. In case the ID is not complete or unique, the application will highlight the locations of all matched TIUs
- Allow users to view location history of the TIUs
- Alert users when a TIU is brought out of bounds or when it runs out of battery

The web application consists of two components: the client side and the server side. The client side will be implemented using modern web technologies such as HTML5, JavaScript, CSS3, and AJAX. The server side could be built upon one of the two most popular web server applications, i.e. Microsoft IIS and Apache.

#### 2.2.2.3 Controller

The controller application is a GUI application that allows an administrator to manage the system. It allows the administrator to

- Modify the geometry of the tracking area
- Remap asset tags’ ID to TIUs’ ID
- Add or remove devices (detectors and asset tags)

The controller also receives RSSI data from the proxy, preprocesses them before feeding them into the location engine.

#### 2.2.2.4 Location Engine

The location engine receives RSSI values from the controller and uses those values to calculate the locations of the asset tags. The derived locations will then be stored in the database.
In case of using battery to power the asset tags, this application also receives battery level reports of the asset tags from the detectors and update the data in the database. This application should be written in a programming language that supports SQL database access and network communication.

The controller and the locationing applications are discussed herein as two separate applications. However, they can definitely be combined into one single application.

## 2.3 Hardware

The infrastructure of the tracking system consists of detectors, asset tags, proxies and a server, as shown in Figure 3-6.

Hardware

Figure 3-6: An example topology for hardware infrastructure.

### 2.3.1 Asset Tag

An asset tag consists of two major parts: a microcontroller, and a RF transceiver. The microcontroller controls the RF transceiver. The RF transceiver is responsible for communicating information to the system.

### 2.3.2 Detector

A detector consists of two major parts: a microcontroller, and a RF transceiver. The microcontroller controls the RF transceiver. The RF transceiver is responsible for communicating information to the system.

### 2.3.3 Proxy

The proxy consists of three major parts: a microcontroller, a Wi-Fi transceiver, and an ISM band transceiver. The microcontroller is responsible for relay data between the two transceivers.

### 2.3.4 Parts Consideration

The parts below are our first but not final consideration of possible hardware combinations for this project. This would help us get a first perspective on the hardware solutions and estimate the possible cost of the system. These are selected carefully to make sure they meet these main requirements: small size, low power consumption and low price. Also, it is important that they are available and well-supported.

#### 2.3.4.1 Microcontroller (MCU)

We consider two Atmel MCUs as the main processing units: ATmega and ATtiny.

| Price (USD) | Size (mm) | Active current | Support | Sleep Current
ATmega | 4 | 9x9 | 9mA | Excellent | 1mA
ATtiny | 2 | 5x5 | 6mA | Poor | 1mA

#### 2.3.4.2 RF Transceiver

We consider three transceivers for main communication between the asset tags and the detectors: RFM12, RFM22, and XBee.

| Price (USD) | Size (mm) | Active current | Support | RSSI | RF Band
RFM12 | 7 | 16x16 | 25mA | Excellent | Analog | 433MHz
RFM22 | 12 | 16x16 | 80mA | Poor | Digital | 433/868/915MHz
XBee | 23 | 24.38 x 27.61 | 50mA | Excellent | Digital | 2.4GHz

#### 2.3.4.3 Wi-Fi Transceiver

Part | Source | Price (USD) | Size(mm) | Active Current | Support
WiFly Shield | SparkFun | 89.95 | 65x55 | Rx 40mA Tx 210mA (Max) | Arduino Experimental Library
WiFly GSX | SparkFun | 49.95 | 21x38 | Rx 40mA Tx 210mA (Max) | SMD Chip Boasts EASY integration
MRF24WB0MA | Microchip | 26.57 | 31x18.4 | Rx 85mA Tx 154mA | Requires using PIC microcontrollers to benefit from easy integration

#### 2.3.4.4 Battery

If the asset tags are powered by batteries, coin cell batteries seem to be a preferable choice due to the size of the tag. These are wide available in different capacities and prices

For example, Digi-Key has 3V-1000mAh, 0.96-inch-in-diameter coin batteries at about $3-$4.

Assuming that

- Transmission time: 100ms every 10 seconds
- Active current 100mA (RF transceiver + MCU)
- Negligible sleep current

Then, the approximate battery life is

Battery Life=(1000mAh)/(100mA×(100ms)/(10s))=1000hr≈41days

This shows the battery meets our requirements.

This estimation is reasonable if the RF modules and the microcontrollers support µA sleep modes.

# 3 Work Breakdown Structure

The Work Breakdown Structure (WBS) in Figure 4-1 provides a framework for the development of the TIU Tracking System using a hierarchical tree structure. The first two levels of the WBS (the root node and Level 2) define a set of 6 main tasks (1.0, 2.0, 3.0, 4.0, 5.0, and 6.0) that collectively and exclusively represent 100% of the project scope. At each subsequent level, the children of a parent node collectively and exclusively represent 100% of the scope of their parent node. Each children node should be done in order (Ex: 1.1, 1.2, 1.3, 1.4) to complete the main task (parent node 1.0).

WBS_2

Figure 4-1: Work breakdown structure.

# 4 Road Map

The road map (Figure 5-1) shows main tasks that must be done in this project from January to June. The big arrow represents one month period, and the small arrow represents the dependency among tasks. Example: prototype task must depend on hardware design and software design tasks.

Road_map_3

Figure 5-1: Road map

# 5 Task Schedule

Please see the Gantt chart that was attached to this document.

# 6 Milestones

Milestones_2

# 7 Deliverables

No. | Deliverable | Tentative date
1 | Requirements Specification | Jan 28, 2011
2 | Proposal | Feb 15, 2011
3 | Hardware prototype (breadboard) - Three asset tags - Six detectors - One proxy | Apr 7, 2011
4 | Software prototype - Web application - Controller - Location engine - Proxy firmware - Detector firmware - Asset tag firmware | Apr 7, 2011
5 | Hardware products (PCB) - 10 asset tags - Six detectors - One proxy | Apr 18, 2011
6 | Software product (Release Candidate) - Web application - Controller - Location engine - Proxy firmware - Detector firmware - Asset tag firmware | Apr 18, 2011
7 | Product Design Specifications - Hardware Design - Software Design | Apr 21, 2011
8 | Documentations - System maintenance - User guide | May 25 2011
9 | Final presentation and demonstration | Jun 6, 2011
10 | Poster competition | Jun 7, 2011

# 8 System Requirements

## 8.1 Hardware Requirements

No. | Device | Quantity
1 | Asset Tag | 10
2 | Detector | 6
3 | Proxy | 1
4 | Server | 1

## 8.2 Software Requirements

No. | Software | Quantity
1 | Microsoft Windows operating system | 1
2 | Web server (IIS or Apache) | 1
3 | Development tools | N/A

# 9 Project Cost

## 9.1 Microcontroller

There are many possible microcontrollers we could use to implement a solution. The ATmega 328 is a good choice because they are the Arduino technology platform. However, if under testing we discover power to be an issue, we have the possibility to move to a smaller ATtiny. The average price for any microcontroller we would consider will be between $2 and $5.

## 9.2 RF Transceiver

The RF transceivers vary widely in capability and cost. More testing will need to be conducted before we fully understand the characteristics and implications of each transceiver. The most inexpensive transceiver runs for around $7, and the most expensive is around $20.

## 9.3 Wi-Fi Transceiver

The Wi-Fi transceiver benefits from the fact that we need only one to complete the overall prototype. In general, a wisely configured system should not require many of these, relative to other hardware modules. The cost of the transceiver, therefore, has less impact on the overall cost of the system. In general, these devices run between $30 and $90.

## 9.4 Server Computer

Included in the cost tabulation is the price for a server computer that executes all the back-end software. We do not expect numerical processing to be an extreme burden, and therefore do not require a high end computational platform. An entry level consumer PC can provide the necessary power required and costs on average $400.

## 9.5 Total Cost Estimation

Table 10-1 shows the upper bound cost estimation of the tracking system.

Table 10-1: Upper bound cost estimation

No. | Manufactory | Description | Qty | Unit Price (USD) | Amount (USD)
| TOTAL | | | | 1255.00
A | HARDWARE | | | | 1255.00
A1 | Asset Tag | | | | 450.00
1 | | MCU | 10 | 5.00 | 50.00
2 | | RF Transceiver | 10 | 20.00 | 200.00
3 | | Other (battery, components, …) | 10 | 20.00 | 200.00
A2 | Detector | | | | 270.00
1 | | MCU | 6 | 5.00 | 30.00
2 | | RF Transceiver | 6 | 20.00 | 120.00
3 | | Other (battery, components, …) | 6 | 20.00 | 120.00
A3 | Server | | | | 400.00
1 | | Computer | 1 | 400.00 | 400.00
A4 | Proxy | | | | 135.00
1 | | MCU | 1 | 5.00 | 5.00
2 | | RF Transceiver | 1 | 20.00 | 20.00
3 | | Wi-Fi Transceiver | 1 | 90.00 | 90.00
4 | | Other (battery, components, …) | 1 | 20.00 | 20.00
B | SOFTWARE | | | | 0.00
1 | | Web Server | 1 | 0.00 | 0.00
2 | | Development Tools | 1 | 0.00 | 0.00

# 10 Conclusion

The tracking system consists of two primary parts: hardware and software. The hardware infrastructure is built upon RF technology. The number of detectors will be scaled in order to achieve the desired accuracy and efficiency. The locating algorithm is in software, and more experimenting will have to be conducted until we know for certain how we will implement it, but we are confident that we will converge upon a solution.

# 11 Appendices

Include relevant information as needed to support the proposal. Appendices should include:

- Requirements specification document approval with original signatures
- Gantt chart

Portland State University Capstone 2011 16

Portland State University Capstone 2011 1

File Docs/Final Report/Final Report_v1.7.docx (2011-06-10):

Portland State University

Department of Electrical and Computer Engineering

11

Capstone 2011

TIU Tracking Final Report

Sponsor: Intel

Advisor: Prof. Robert Daasch

Members: Dung Le

Tri Truong

Lynh Pham

Man Hoang

Daniel Ferguson

Version History

Version | Implemented By | Revision Date | Approved By | Approval Date | Reason
1.0 | Daniel Ferguson | 05/02/2011 | | | Report outline
1.2 | Tri Truong Lynh Pham | 05/27/2011 | | | Draft
1.3 | Dung Le Tri Truong Lynh Pham Daniel Ferguson | 06/05/2011 | | | Modify report
1.4 | Man Hoang | 06/07/2011 | | | Added Web App Improve formatting
1.5 | Dung Le Tri Truong Lynh Pham Man Hoang Daniel Ferguson | 06/08/2011 | | | Modify report
1.6 | Dung Le Tri Truong Lynh Pham Man Hoang Daniel Ferguson | 06/09/2011 | | | Review structure, discussions and recommendations
1.7 | Dung Le Tri Truong Lynh Pham Man Hoang Daniel Ferguson | 06/10/2011 | | | Final report

Abstract

TIU tracking system is a capstone project conducted by Portland State University students and sponsored by Intel Corp. The system will be used to track locations of Test Interface Units (TIUs) in the Intel Validation Lab.

In this paper, we propose a general architecture for the tracking system. The main goal of the architecture aims to achieve a low-cost, yet effective tracking system. The infrastructure of the tracking system is built upon RF transceivers which communicate wirelessly in a mesh network. The asset tags will be attached to tracked devices (TIUs). These asset tags will broadcast messages to detectors. Messages that contain received signal strength indication (RSSI) values will be routed though the mesh network to a server. The server will analyze the received data, calculate the locations, and store them in the database. A web app will then be able to access the database and display location information in an interactive 2D map.

The primary figures of merit that were used in the decision making process include accuracy, power consumption, size, and cost. The last administrative idiom this paper conveys is a road map which will guide our team to the final objective. The means by which this is accomplished is through a tentative schedule, timeline, a list of milestones and expected deliverables.

# 1 Introduction

Location aware computing has a bright future in the fields of personal navigation, personal security, prompt healthcare and entertainment. Furthermore, information on the physical location of mobile nodes can greatly help in urban search and rescue missions, as well as enable geographical routing in ad hoc multi-hop networks. The determination of physical location is sometimes referred to as location estimation, location identification, localization, and positioning or geolocation identification.

As part of this effort, Intel wants to automate tracking of the Test Interface Units (TIU) at different locations of the Intel lab, with the intention of wirelessly locating a TIU’s physical position at all times. Given the size and complexity of Intel validation lab, locating Test Interface Units (TIU) can be a tedious task since the test equipments have to be broken down to identify the TIU it is using. Therefore, an effective TIU tracking system rises as an urgent need.

By tracking location of the TIU’s physical position in the lab, Intel can minimize downtime and decrease labor costs caused by the size and complexity of Intel validation lab. This solution enables:

- Increased equipment utilization
- Decreased loss and theft
- Reduced costs
- Faster production
- Avoid time wasted on manual searches and inventory checks.

This capstone project will be a prototype system that can wirelessly track the location of at least 10 TIUs in an indoor environment. The duration of the project will last 6 months.

# 2 Specification

## 2.1 System Overview

Figure below shows a network of detectors that are geometrically located in a grid array. The density of the grid array will primarily be a ratio of accuracy and cost. For the scope of this project, the reasonable number of detectors would be from five to seven. The location of the proxy must be within range of at least one detector.


There are two distinct networks which compose this system: the front-end network, which includes all the physical nodes, and the back-end network, which includes all the logical nodes. The proxy is the gateway between the two networks.


There are three important aspects to the communications that take place in the front-end network.

- Each asset tag will broadcast a message periodically. Neighboring detectors will detect the broadcast, and determine the RSSI of the broadcasting asset tag.
- When a detector determines the RSSI of a broadcasting asset tag, it must then transmit this data towards the proxy using a routing table. The routing table will be configured in such a way as to ensure the data moves in a direction that is physically towards the proxy.
- The locating application will periodically receive bursts of RSSI information from various detectors. Since it has no knowledge of how many detectors actually detected a broadcasting asset tag, it will wait a certain amount of time that assumes all the RSSI information from the various detectors has finished coming in.

Now we will further discuss some finer points of the second aspect. Figure below shows the paths taken as a result of an asset tag’s broadcasting. When an asset tag broadcasts, the nearest detectors are able to determine the corresponding RSSI values. The detectors that detected the asset tag broadcast are denoted by a connection with a green arrow. Each detector will have a routing table programmed into them. The routing table will contain information that steers the messages physically toward the proxy. In the example shown in Figure below, the routes taken are in red. The blue dash paths are routes that exist but are not taken.


## 2.2 Software

### 2.2.1 Front-end Software

This section describes the firmware that is programmed into the tags, detectors and proxy. The codes are adapted to Arduino platform, using Arduino and RF12 library (provided by Jeelabs)

#### 2.2.1.1 Basic Communication

The below functions are provided by Jeelabs rf12 library for basic communicating purposes:

Function | Description
rf12_initialize() | Init radio module
rf12_recvDone() | Keep the reception and transmission going
rf12_sendStart() | Switch to transmission mode and send a packet
rf12_lowbat() | This checks the status of the RF12 low-battery detector
rf12_canSend() | Check if radio is ready to send data

##### 2.2.1.1.1 Tag

Tag is typically in a low power sleep mode. It periodically wakes up, broadcasts its ID and battery level, then goes back to sleep.

Initialize MCU & Radio

Broadcast

Sleep

Battery check

Note:

- Tag performs battery check at beginning of every cycle, battery threshold: 3.2V
- Radio is initialized to broadcast at 433MHZ, -15dB, 49.2kbps, and 1 second sleep time.
- Each tag needs a unique ID

##### 2.2.1.1.2 Detector

Detectors are responsible for:

- Picking up data from tags, determine tag’s signal strength, and transmitting them to nearby detectors or the proxy.
- Picking up data from other detectors and transmitting them to nearby detectors or the proxy.

Initialize MCU & Radio

Listening for packet

Battery check

Read RSSI

Construct new packet

From tag?

Yes

Modify packet route

No

Transmit packet

Notes:

- Detectors are always awake listening to tags and other detectors
- RSSI values are read from analog input (analogRead() - Arduino library function). MCU has 10-bit analog to digital converters.
- Data packets are defined in the Mesh protocol below
- Radio is initialized to broadcast at 433MHZ, 0dB (max), 49.2kbps

##### 2.2.1.1.3 Proxy


Initially, the proxy configures the MCU, RF12 and Wifly modules. Configuring the MCU and RF12 is a standard process. The process used to configure the Wifly is unique. Configuring the Wifly involves setting it to connect to an Ad-Hoc network that has already been created on the controller computer. In order to do so, the Wifly must be told what the WPA password is.

There are other methods to configure the Wifly, but in general, the main goal is to get the Controller computer and proxy connected to each other via a TCP/IP connection. The WiFly module has very good documentation located at

http://www.sparkfun.com/datasheets/Wireless/WiFi/WiFlyGSX-um2.pdf

http://forum.sparkfun.com/viewtopic.php?f=32&t=25129 http://www.sparkfun.com/datasheets/Wireless/WiFi/rn-131-ds.pdf

#### 2.2.1.2 Power Management

##### 2.2.1.2.1 Battery Life

- C is the capacity of battery (mAh)
- I is the active current (mA)
- D is duty cycle, which is transmission time / transmission cycle

Battery Life=C/(I×D)

We have this on the assumption that we ignore the sleep current.

For example, assuming that:

- Transmission time: 100ms every 10 seconds
- Active current 100mA (RF transceiver + MCU)
- Negligible sleep current

Approximate battery life is

Battery Life=(1000mAh)/(100mA×(100ms)/(10s))=1000hr≈41days

##### 2.2.1.2.2 Transmission Time

It is good to know the transmission time of the module so that we can calculate the transmission ratio. Also, transmission time place an important role in collision avoidance (the shorter transmission time, the smaller chance of collision).

Transmission time=Overhead+(Number of transmitted bytes×8/Baudrate)

##### 2.2.1.2.3 Sleep Mode

The sleep mode (implemented on tags) exploits power-down mode in ATMega328P and uses watchdog timer to periodically wake up the chip. The ATMega328P is Pico-power version. Below is the DC characteristic from datasheet:

Below is the reference for sleep mode and wake up source


Below are the register bits for setting up power-down mode:


Initialize MCU/Radio/WDT

Broadcast

Turn radio off

Battery check

Sleep

Turn radio on

WDT interrupt/Wakeup

Note:

- MCU sleep mode implementations provided AVR library (avr/sleep.h)
- Radio sleep mode implementations provided by rf12 library (rf12_sleep())

#### 2.2.1.3 Mesh Protocol

For a detector to determine the RSSI of an asset tag, the asset tag must broadcast a message. The message has eight fields. The way the fields are used depends on the origin of the message. There are two possible origins of a message. The first type of origin is an asset tag. A message can be identified as coming from an asset tag by examining the DID value field. If the field contains the value zero, then the message originates from an asset tag. Otherwise, the message originates from a detector.

When receiving a message whose DID is zero, it assumes the origin is a tag, and it will act accordingly:

1. Replace the DID of the message with its own ID
2. Replace the SID of the message with its own ID
3. Replace the RSSI value with that inferred from the reception of the asset tag broadcast
4. Replace the Detector Battery level with that of its own.
5. Rebroadcast the message

When receiving a message whose DID is not zero, it assumes the origin is another detector, and it will act accordingly:

6. Replace the SID of the message with its own ID
7. Rebroadcast the message

An example of this message passing sequence is show in below figure.


### 2.2.2 Back-end Software

The back-end network, composed exclusively of logical nodes, will rely on normal internet communication. This allows applications to leverage TCP/IP and many APIs that have been built upon it. Also, we gain the advantage of being able to have standard inter-nodal communication regardless of if they exist on the same computer or not. This increases the scalability of the system.

The back-end software system consists of four components:

- SQL Database
- Web App
- Controller
- Location Engine

#### 2.2.2.1 SQL Database

The SQL database is a central component that provides a link among the web app, the controller, and the location engine. Specifically, the database stores the following data:

- Location update interval
- Identifications, locations, and battery levels of the detectors
- Identifications, locations, and battery levels of the TIUs
- Mapping table between asset tags’ ID and TIUs’ ID

We agreed on using SQL since it is a standard that is easy to use, secure and scalable.

#### 2.2.2.2 Web App

The web app provides an interface for users to access the location information in the database. Its functionalities are:

- Display the locations and battery levels of all tracked TIUs on an interactive 2D map
- Allow users to search for a TIU via its ID. In case the ID is not complete or unique, the application will highlight the locations of all matched TIUs
- Allow users to view location history of the TIUs
- Allow an administrator to add, modify, and remove tags and detectors
- Allow an administrator to configure the tracking area

Technologies used:

- PHP
- HTML5, CSS3, JavaScript, AJAX

##### 2.2.2.2.1 Structure

The figure below shows the overall structure of the Web App.

MySQL Database

Common.php

TIUTracking.php

Common.js

FlexTable.js

InfoBox.js

Main.js

Map.js

TabControl.js

Timer.js

Vector2D.js

fx.js

Common.css

TIUTracking.css

MapUpload.php

Images

Request.php

- Common.php
  - Contains database information (host, name, username, password)
  - Declares global constants
  - Implement helper functions to be used in Request.php and MapUpload.php
- Request.php
  - The main client-server interface that handles all requests from client except configuring the tracking area (see Client-Server Communications section)
- TIUTracking.php
  - The main client interface that interacts directly with users
- MapUpload.php
  - Handles the configuration of the tracking area
  - Allows an administrator to change the map resolution and upload a new map image
- Common.css
  - Contains common CSS styles used in TIUTracking.php and MapUpload.php
- TIUTracking.css
  - Contains CSS styles dedicated to TIUTracking.php
- Images folder
  - Contains images used in TIUTracking.php and MapUpload.php
  - Contains the map image
- Common.js
  - Declares global constants and utility functions used in other JavaScript files
- FlexTable.js
  - Implements TFlexTable class, a flexible table that creates, modifies, and deletes cells on demand
- InfoBox.js
  - Implements TInfoBox class, which is used to display tags’ and detectors’ info in a tooltip-like manner
- Main.js
  - The main script handles the dynamic contents of TIUTracking.php as well as communicating with the server
- Map.js
  - Implements TMap class, an interactive 2D map with smooth zooming and panning
- TabControl.js
  - Implements TTabControl class, which adds logics to a tab panel
- Timer.js
  - Implements TTimer class, which is used to create the animation of the map as well as to periodically send request to the server for new tags’ info
- Vector2D.js
  - Implements TVector2D class, which is used in Map.js
- fx.js
  - An open source animation library from http://fx.inetcat.com/
  - It has been modified to improve the efficiency (speed and memory)

##### 2.2.2.2.2 Client – Server Communications

This section discusses the format of the requests and their corresponding responses that are handled by Request.php.

The response is in JSON format and consists of three fields:

Field | Type | Description
request | String | Request identifier. This is the value of the request parameter.
status | Integer | 0 = No Error 1 = Session End 2 = Invalid Argument
data | Object | If status is 0, this field contains the returned data for the corresponding request and its type is request specific (see the following table). Otherwise, it is an error message.

The following table describes all the requests handled by Request.php and the value of data field of the corresponding responses on success.

Request | Params | Value of ‘data’ field on success
Log in | request = log-in username = ... password = ... | Zero (SessionID regenerated, username cookie set)
Log out | request = log-out | Zero (All cookies cleared)
Get tags’ info | request = get-tags | [ { s: String, // Timestamp i: Integer, // Tag ID a: String, // Asset ID x: Double, // X coordinate y: Double, // Y coordinate b: Integer // Battery info }, ... // For other tags {} // End of array ]
Add tag | request = add-tag tag-id = ... asset-id = ... | { s: String, // Timestamp i: Integer, // Tag ID a: String, // Asset ID x: Double, // X coordinate, default -1 y: Double, // Y coordinate, default -1 b: Integer // Battery info }
Delete tag | request = del-tag tag-id = ... | ID of the deleted tag
Get detectors | request = get-detectors | [ { i: Integer, // Detector ID x: Double, // X coordinate y: Double, // Y coordinate b: Integer // Battery info }, ... // For other detectors {} // End of array ]
Add detector | request = add-detector detector-id = ... x = ... y = ... | { i: Integer, // Detector ID x: Double, // X coordinate y: Double, // Y coordinate b: Integer // Battery info }
Delete detector | request = del-detector detector-id = ... | ID of the deleted detector

#### 2.2.2.3 Controller

The controller has two major modes of operation

1. Calibrating
2. Locating

In addition to the two main operating modes, it also has logging capabilities to allow for simple diagnostics.

In calibrating mode, a Tag is placed in a known location, and data, representing an RF fingerprint, is collected and stored in an offline database. An x and y coordinate, tag Id, and calibration block id must be specified for each calibration block. If there are multiple tags currently in operation within the tracking region, the controller will ignore the tags that are not specified for calibration.


In locating mode, the controller collects and sorts incoming data, based on Tag Id, into “buckets”. Once a bucket is filled, it is handed to the location engine for location calculation. The result from the location engine is then stored into the database for future retrieval by the web application.

#### 2.2.2.4 Location Engine

The location engine receives RSSI values from the controller and uses those values to calculate the locations of the asset tags. The location engine employs fingerprint algorithm which compares tag RSSI to sets of calibrated RSSI to find a best matching set. This is based on the fact that each location has a unique and consistent RSSI pattern. Since the calibrated RSSI set is associated with a calibrated location, the engine can use this result to provide location of the tag.

Data recorded from calibrating are RSSIs from a tag placed at the calibrating location (these signals measured by the surrounding detectors).

##### 2.2.2.4.1 Euclidean Distance Method

Fingerprint matching uses Euclidean distance calculated as follow:

d=√(∑_(i=1)^N (RSSI_(li) -RSSI_(ci) )^2)

Where:

- d is Euclidean distance
- N is number of detectors
- RSSI_(li) is the RSSI value from detector i in locating phase
- RSSI_(ci) is the RSSI value from detector i in calibrating phase

The minimum Euclidean distance from the set of calculated distances indicated a best matching result.

##### 2.2.2.4.2 Aliasing

Aliasing is an issue of the fingerprint approach since two arbitrary locations can accidentally have a similar RSSI pattern, resulting in similar Euclidian distances. This causes incorrect or unstable output results.

To address aliasing, the algorithm needs to determine whether there are possible aliasing results in the calculated Euclidean distance set. If there is such case:

- If the locations are close to each others, then the algorithm chooses to interpolate their locations to provide location of tag.
- If the two locations are not close to each others, the algorithm will decide to referencing the nearest detector using the strongest RSSI in the calibration set before determining the location of tag

##### 2.2.2.4.3 (n -1) Supporting Model

Locating algorithm uses a so-called (n-1) model to support its decisions. The (n-1) model performs n Euclidean distance calculations on n-1 RSSI values of the incoming RSSI set and at each time, an RSSI value from a detector is left out. This will give n results. Since there are less RSSI in used, prediction from this model will likely to:

- Support the main algorithm when it is unsure about a decision
- Eliminate effect of bad data from single detector

The core algorithm is described as in the below flow chart.

Calculate Euclidean distances

Sort distance list

Aliasing?

Yes

Referencing (n-1) model

No

Adjacent locations?

Interpolating

Referencing nearest detector

No

Yes

Give Tag location

Note:

- Calculations are performed using an input packet associated with a tag
- Calibrated data needs to be provided before calling locating method

##### 2.2.2.4.4 Input & Output Filters

Input filter use previous input to predict noise in the current input packet. If the filter finds that input is unstable, it will ignore the packet and return the previous location of tag.

The output filter’s purpose is to provide stabilized output by having a moving average of the past N location calculations.

Data flow diagram:

Extract input packet from controller

Compare to previous packet

Is stable?

Yes

Retrieve previous tag location

No

Send to fingerprint engine

Send Tag location to output filter

Store tag location (engine output)

## 2.3 Hardware

The system consists of three main devices: tags, detectors and proxy. Tag is attached to the tracking asset and broadcast its data to detectors. Detectors are at fixed locations, they receive data from tag or from another detector. All data will be relayed toward proxy by detectors. For system mobility, proxy is a standalone module that connects to local wireless LAN and relays data to back-end system. Since the system requires large range of tracking, tags, detectors and proxy are active broadcasting devices and need to be powered from power source.

Front-end system devices use RF technologies for communicating and locating. Data that travel through the front-end system contain device info which is used for device identification and location calculation. The primary datum used for location calculation is the Received Signal Strength Indication (RSSI) (measured by detector as receiving a broadcast from a tag. The hardware is designed to give reliable signal strength reading as well as data transferring.

### 2.3.1 Tag

An asset tag consists of two major parts: a microcontroller, and a RF transceiver. The microcontroller controls the RF transceiver. The RF transceiver is responsible for communicating information to the system.

Tags are attached to TIUs. They are the beacon with which locations can be calculated. It is critically important that tags preserve power. Therefore they are typically in a low power state, but periodically wake up to broadcast, and then immediately go back to their low power state.

An asset tag consists of two major parts:

- Microcontroller: ATMega328P – 32 TQFP
- RF transceiver: RFM12B-S2 Wireless Transceiver Module

Table 1: Tag Specifications

Specification | Description
Microcontroller | ATMega328P – 32 TQFP
RF Transceiver | RFM12B-S2 Wireless Transceiver
Voltage regulator | XC6221
Power supply | 6V Battery (two 3-V coin cells in holder)
Program Interface | ISP 6-pin header
Operating Frequency Band | ISM 433 MHz
Power Indicator | No
RF Indicator | No
PCB size | 0.9930 X 1.0030 inches
Microcontroller | 25.4mm x 25.4mm
RF Transceiver | 20.3mm x 25.4mm
Outline Dimension | 1” x 1” x 1”

Table 2: Electrical Characteristics

Specification | Min | Typ | Max | Unit
Power Supply | 3.3 | | 6.0 | V
Transmit Current | | 30 | | mA
Idle Current | | 40 | | µA
Power Dissipation | 99 | 99 | 99 | mW
Operating Temperature | -25 | | +85 | ⁰C

The microcontroller controls the RF transceiver. The RF transceiver is responsible for communicating information to the system.

Board layout of the controller module on a tag

Board layout of the RF module on a tag

### 2.3.2 Detector

Detectors are responsible for gathering RSSI data for the locating algorithm. They must always be listening for a tag to broadcast. Upon receiving a broadcast from a tag, or another detector, it rebroadcasts the message, which results in messages always propagating toward the proxy.

A detector consists of two major parts: a microcontroller, and a RF transceiver. The microcontroller controls the RF transceiver. The RF transceiver is responsible for communicating information to the system.

- Microcontroller: ATMega328P – 28 DIP
- RF transceiver: RFM12B-S2 Wireless Transceiver

Table 3: Detector Specifications

Specification | Description
Microcontroller | ATMega328P – 28 DIP
RF Transceiver | RFM12B-S2 Wireless Transceiver
Voltage regulator | MIC5205 150mA Low-Noise LDO Regulator
Power supply | 9V Battery
Program Interface | ISP 6-pin header
Operating Frequency Band | ISM 433 MHz
Power Indicator | Yes (regular red LED)
RF Indicator | Yes (green LED)
PCB size | 25.4mm x 88.9mm
Outline Dimension | 3.5” x 1”

Table 4: Electrical Characteristics

Specification | Min | Typ | Max | Unit
Power Supply | 3.3 | 9.0 | 16.0 | V
Transmit Current | | 30 | | mA
Receive Current | | 30 | | mA
Idle Current | | 30 | | mA
Power Dissipation | 99 | 99 | 99 | mW
Operating Temperature | -25 | - | +85 | ⁰C

Board layout of a detector

### 2.3.3 Proxy

The proxy plays the role of relay all data from detectors and delivers them to the controller. The proxy consists of a RF end which interfaces with RF front-end network. The other end has Wi-Fi module which will be connected via TCP/IP. The microcontroller is responsible for receiving data from the RF12, and transmitting data through the Wifly.

The proxy consists of three major parts:

- Microcontroller: ATMega328P – 28 DIP
- RF transceiver: RFM12B-S2 Wireless Transceiver Module
- Wi-Fi transceiver: WiFly GSX Module

Table 5: Proxy Specifications

Specification | Description
Microcontroller | ATMega328P – 28 DIP
RF Transceiver | RFM12B-S2 Wireless Transceiver
Voltage regulator | LM317
Power supply | 6V Battery
Program Interface | USB
Operating Frequency Band
RF Transceiver | ISM 433 MHz
Wi-Fi Transceiver | 2.4 GHz Standard
Power Indicator | Yes
Transmission Indicator | Yes
Outline Dimension | Prototype on bread board

Table 6: Electrical Characteristics

Specification | Min | Typ | Max | Unit
Input Voltage | | | 3.3V | V
Current Draw | | 200 | | mA
Operating Temperature | -25 | | +85 | ⁰C

### 2.3.4 Parts Selection

These are selected carefully to make sure they meet these main requirements: small size, low power consumption and low price. Also, it is important that they are available and well-supported.


RFM12B-S2 Wireless Transceiver Module | WiFly GSX Breakout | ATMega328P – 28 DIP | ATMega32P – 32 TQFP

Refer to datasheets provided by manufacturers for more information (See Useful Links section in Appendices).

# 3 Test Plan

## 3.1 Unit Tests

### 3.1.1 Power Supply

Test Writer: Lynh Pham
Test Case Name | Power Supply Unit | Test ID #: | Pwr_01
Description: | Measure output voltage of voltage regulator. Input voltage is supplied by power supply in capstone lab. Record output voltage versus input voltage values. | Type: | [x] white box [ ] black box

Tester Information
Name of Tester: | | Lynh Pham | | Date: | | | 5/6/2001
Hardware Version: | | Voltage regulator Mic5205 | | Time: | | | 1:00pm
Setup: | | Connect voltage meter to jumper VCC output (JP_PWR) to measure output voltage
Test | Input Voltage | Expected Output | Pass | | Fail | N/A | Comments
1 | Check the red LED | Should be on with the connected jumper | x
2 | Connect 6V DC (4xAA batteries) to power jack | Output should be 3.3V+3% | x
3 | Connect 9V DC battery to power jack | Output should be 3.3V+3% | x
4 | Connect 9V adapter to power jack | Output should be 3.3V+3% | x
Overall test result: | | | x

Tester Information
Name of Tester: | | Lynh Pham | | Date: | | | 5/6/2011
Hardware Version: | | Voltage regulator XC6221 | | Time: | | | 1:10pm
Setup: | | Connect voltage meter to jumper VCC output (JP_PWR) to measure output voltage
Test | Input Voltage | Expected Output | Pass | | Fail | N/A | Comments
1 | Check the red LED | Should be on with the connected jumper | x
2 | Connect 6V DC (4xAA batteries) to power jack | Output should be 3.3V+3% | x
3 | Connect 6V DC battery to power jack | Output should be 3.3V+3% | x
Overall test result: | | | x

### 3.1.2 Tag

Test Writer: Lynh Pham
Test Case Name | Asset Tag Electrical Testing | Test ID #: | Tag_01
Description: | Checks the asset tag responding RSSI outputs. | Type: | [x] white box [ ] black box

Tester Information
Name of Tester: | | Lynh Pham | | Date: | | | 5/6/2011
Hardware Version: | | Asset tag | | Time: | | | 1:20pm
Setup: | | Remove the breakout board then connect the programmer cable to the SPI on the board. Power the testing board. Connect the base station to a PC by USB cable.
Step | Action | Expected result | Pass | | Fail | N/A | Comments
1 | Compile the final firmware version. | Arduino software should generate no warning/error | x
2 | Download firmware to MCU | AVR Studio should generate no error | x
3 | Turn off power
4 | Remove the cable from SPI
5 | Insert the breakout board into the tag
6 | Turn on power
7 | Open software controller | A new window should open | x
8 | Click Start | RSSI signal should be showed up on the window with Tag ID | x
9 | Repeat step 1-8 for other tags | | x
Overall test result: | | | x

### 3.1.3 Detector

Test Writer: Lynh Pham
Test Case Name | Detector Electrical Testing | Test ID #: | Det_01
Description: | Checks the detector receiving RSSI from the asset tag. | Type: | [x] white box [ ] black box

Tester Information
Name of Tester: | | Lynh Pham | | Date: | | | 5/6/2011
Hardware Version: | | Detector | | Time: | | | 1:40pm
Setup: | | Connect the programmer cable to the SPI on the board. Power the testing board and an asset tag. Connect the base station to a PC by USB cable.
Step | Action | Expected result | Pass | | Fail | N/A | Comments
1 | Check the red LED | Should be on when turn the power switch on | x
2 | Compile the final firmware version. | Arduino software should generate no warning/error | x
3 | Download firmware to MCU | AVR Studio should generate no error | x
4 | Turn off power | The red LED should be off | x
5 | Remove the cable from SPI
6 | Turn on power | The red LED should be on | x
7 | Open software controller | A new window should open | x
8 | Check the green LED | Should be blinking with the connected jumper | x
9 | Click Start | RSSI signal should be showed up on the window with detector ID and Tag ID | x
10 | Repeat step 1-9 for other detectors | | x
Overall test result: | | | x

## 3.2 Integration Tests

### 3.2.1 RF Network and Proxy Communication

Test Writer: Dung Le
Test Case Name | RF network and Proxy communication testing | Test ID #:
Description: | Test functionality of RF network and Proxy. Use Wi-Fi proxy to relay all data from detectors to the controller. | Type: | [x] white box [ ] black box

Tester Information
Name of Tester: | | Dung Le | | Date: | | | 5/22/2011
Hardware Version: | | Detector | | Time: | | | 11:00am
Setup:
Step | Action | Expected result | Pass | | Fail | N/A | Comments
1 | Program one tag and one detector with test IDs and transmit interval of 1 second | | x
2 | Turn on tag, detector and proxy | Detector blinking every 1 second | x
3 | Open controller | | x
4 | Turn on proxy to local network | The output console window says “HELLO” | x
5 | Use controller to collect data | data on output console window | x
Overall test result: | | | x

### 3.2.2 Fully Integrated System

Test Writer: Daniel
Test Case Name | Locating with multiple detectors testing | Test ID #:
Description: | Test functionality of the tracking system with one tag, multiple detectors and proxy. Calibrating and Locating procedures are conducted. Locations of tags are display on 2D map on Web app which exploited data from database on CAT server. Location: capstone lab | Type: | [x] white box [ ] black box

Tester Information
Name of Tester: | | Daniel | | Date: | | | 5/22/2011
Hardware Version: | | Detector, Tag, Proxy (PCB) | | Time:
Setup:
Step | Action | Expected result | Pass | | Fail | N/A | Comments
1 | Program tag and detectors with IDs and transmit interval of 1 seconds
2 | Power up tag and detectors, then distribute detectors at four corners of the lab | Detector’s LEDs blink at approximately 1 second | x
3 | Open the controller
4 | Place tag at 1st location
5 | Calibrate | Calibrated blocks shown on controller | x
6 | Repeat 3-4 (total 4 locations)
7 | Place tag at 1st location (exact)
8 | Locate | Tag’s locations shown on controller | x
9 | Repeat 7-8 (total 4 locations)
Overall test result: | | | x | | | | 3/4 locations are located correctly

## 3.3 Acceptance Tests

### 3.3.1 Tag’s Size

Test Writer: Lynh Pham
Test Case Name | Tag’s Size testing | Test ID #:
Description: | Using ruler to measure the actual size of asset tag (PCB). The required size of a tag must be 1” x 1” x 1”. | Type: | [x] white box [ ] black box

Tester Information
Name of Tester: | | Lynh Pham | | Date: | | | 5/6/2011
Hardware Version: | | Tag (PCB) | | Time: | | | 1:45pm
Setup: | | Prepare three tags and ruler for measurement.
Step | Action | Expected result | Pass | | Fail | N/A | Comments
1 | Measure one tag’s size | 1” x 1” x 1” | x | | | | 0.9930” x 1.0030”
2 | Repeat measurement with two more tags
3 | Average size | | | | | | 1” x 1” x 1”
4
Overall test result: | | | x

### 3.3.2 Power

Test Writer: Lynh Pham
Test Case Name | Consumed power of asset tag | Test ID #:
Description: | Measure power consumed by a tag during stressed testing condition in order to predict battery lifetime of the asset tag. Expected battery lifetime is more than one month with normal operating conditions. | Type: | [x] white box [ ] black box

Tester Information
Name of Tester: | | Lynh | | Date: | | | 5/6/2011
Hardware Version: | | Tag (PCB) | | Time: | | | 1:50pm
Setup: | | A tag with 1 sec broadcast interval, 3ms transmit window, multi-meter
Step | Action | Expected result | Pass | | Fail | N/A | Comments
1 | Insert 2 coin cell batteries
2 | Power a detector
3 | Check the green LED | Should be blinking | x
4 | Use a multi-meter measure voltage of coin cell batteries | Should be 6.4V at beginning | x
5 | Repeat step 4 every 12 hours until the voltage drop below 3.3V | The voltage should decrease a little bit. The batteries should be last long 76 days | x
Overall test result: | | | x

### 3.3.3 Accuracy

Test Writer: Tri Truong
Test Case Name | Accuracy of the tracking system testing | Test ID #:
Description: | Test the accuracy of the tracking system by evaluating the error of the calculated results returned by the controller during locating process. Test with four detectors and one tag at Smith Food Court, PSU campus. Expected accuracy is 1.5m. | Type: | [x] white box [ ] black box

Tester Information
Name of Tester: | | Daniel – Dung Le | | Date: | | | 5/22/2011
Hardware Version: | | Detector, tag (PCB), proxy (prototype) | | Time:
Setup: | | Set up four detectors in the 12m x 6m tracking area as shown in Figure xx.
Step | Action | Expected result | Pass | | Fail | N/A | Comments
1 | Program tag and detectors with IDs and transmit interval of 1 seconds
2 | Power up tag and detectors, then distribute detectors at four corners of the lab | Detector’s LEDs blink at approximately 1 second | x
3 | Open the controller
4 | Open web app and configure detectors location | | x
5 | Place tag at 1st location
6 | Calibrate | Calibrated blocks shown on controller | x
7 | Repeat 3-4 (total 18 locations)
8 | Place tag at 1st location (exact)
9 | Locate | Tag’s locations shown on web app | x
10 | Repeat 8-9 (total 18 locations) | Detector’s LEDs blink at approximately 1 second | x
Overall test result: average accuracy ~2m | | | x | | | | See result below

Setup:

Detector are set up as shown in the below figure. Calibration points are marked with corresponding block ID numbers. In this tracking area, we use four detectors and calibrate on 15m x 6m area with 3m x 3m grid. Hence, the total number of calibration points is 18 points.


Figure 3-1: Layout of the tracking area – Smith Food Court, SMSU

The error of measurement at each locating point was recorded. The error is defined as the Euclidean distance between the actual location and calculated location. The measurements were conducted at exact calibration points, 0.5m, and 1m far away from the calibration points.

| Location | | Error as distance (m)
Block ID | X | Y | Exact | 1m | 0.5m
100 | 2 | 2 | 0 | 0.5 | 2.5
200 | 2 | 5 | 0 | confused | 2.5
300 | 2 | 8 | confused | 3 | 4
400 | 5 | 2 | 0 | 2 | 0.5
500 | 5 | 5 | 0 | 2 | 2.5
600 | 5 | 8 | 0 | 2.5 | 0.5
700 | 8 | 2 | 0 | 2.2 | 2.5
800 | 8 | 5 | 0 | 2.5 | 1
900 | 8 | 8 | 0 | 4 | 3
1000 | 11 | 2 | 0 | 2.2 | 2.5
1100 | 11 | 5 | 3 | 3 | 3
1200 | 11 | 8 | 0 | 2 | confused
1300 | 14 | 2 | 0 | 1 | 4
1400 | 14 | 5 | 2 | 5 | 3
1500 | 14 | 8 | 0 | 4 | 1
1600 | 17 | 2 | 0 | 2.2 | 3
1700 | 17 | 5 | 0 | 1.8 | 1.5
1800 | 17 | 8 | 0 | 1 | 0.5

Some measurements were noted as “confused” when the calculated location of the tag oscillated between two or more different locations on the map. These oscillations were caused by aliasing of the signal signature in the tracking area, where some locations have nearly the same signal signature.

## 3.4 Final Results

Feasible experiments and acceptance tests were conducted to ensure our design meet the requirements. Technically, the designed TIU tracking system has satisfied basic requirements about size, power, and accuracy. We also conducted experiments with multi-tags and multi-detectors. In such testing, small adjustments of broadcast time interval and transmit window in firmware need to be done to reduce signal collisions. Otherwise, the system will corrupt since message packets will be dropped frequently and the controller will have lack of data to calculate out tags’ locations.

A fully testing with 10 detectors and 8 tags could not be done because of time and space constraint. It is hard to find a large area on campus where we can conduct such experiment. The largest dimension of the area we has had done experiments and testing is about 18m x 8m in Smith Food Court, SMSU, on PSU campus.

### 3.4.1 Device Dimensions

As shown the acceptance test for tags’ size, the physical dimensions of the final products are:

- Tag’s size: 1”x1”x1”
- Detector’s size: 3.5”x1”

The tag’s size satisfies the requirements given by the sponsors. There is no constraint about the size of detectors. With such small size, detectors are quite portable and can be mounted on ceiling of the tracking area.

### 3.4.2 Power Consumption

Because of time constraint, we cannot test the power consumption of a tag in one month. Instead, we applied stressed conditions on tag’s operation which is specified as follow:

- 240mAh coin cell battery
- 30mA transmit current
- 40µA sleep current
- 1sec broadcast interval
- 3ms transmit window
- 0.3% duty cycle

The estimated batter life would be

Lifetime=(240mAh)/(30mA×0.3%+40μA×99.7%)=1,847 hrs=76 days

In reality, a tag will broadcast at lower frequency than stressed broadcast frequency. Hence, the requirement of power consumption of tags can be easily achieved.

### 3.4.3 Accuracy


An accuracy map was plotted to show the error of locating results over the tracking area. The color indicates the error between the actual location and calculated location for each measurement. The number of calibrated points is 18. The number of located points is 54. We did not locate the tag at every location in the tracking area. The colored map is interpolated to show the contour field.

# 4 Discussions

What we have achieved in this project proves the working concept of a RF-based tracking system using fingerprinting method. We have conducted a lot of experiments and iterations during design process within six months; and finally the achievement has demonstrated that our approach is feasible. Technically, our works can be seen as scientific experiments rather than a real industrial process. We had a lot of problems, and we saw that many other issues need to be considered if someone wants to optimize this system and even continue to develop the concept which might be deployed in industrial field.

In order to ensure the tracking system works properly, system configuration should be well-prepared. The way we install detectors in tracking area will affect the performance of the system. In a specific area, detectors should be set up so that broadcasted signal from a tag will be received steadily by a certain number of detectors. It is important because the system needs enough data to compare with calibration data. By experiments we have found out that communication between a tag and a detector has a certain reliable range of signal; outside that range, aliasing will corrupt the calculation in locating phase. An inappropriate settings of detectors will give a bad yield in locating since there will be some regions within which tags cannot be seen by detectors. We called these regions “blind spots”. We haven’t tried with high-density of detectors in tracking area. There is no reason for not using many detectors to ensure they cover tracking area so well but we claim that, besides cost issue, it will reduce the accuracy.

Figure 2: Reliable range of RF signal is about 6-7m

Many aspects of the system need to be tested. Because of time constraint, we can only conduct some tests to ensure the system functions properly as desired. Some experiments actually helped to improve our design based on collected data during testing and debugging phase. We never satisfy with what we intend to do and continuously change methods and even firmware to enhance the performance. It is good to come up with a better solution, but everything must be done at the end of the term. If we have more time, we will test system reliability, calibration density, and evaluate different settings of detectors.

Antenna design is also a critical aspect. In such RF network, antenna plays key role in the performance of the tracking system. We as electrical and computer engineering students have the lack of knowledge about antenna design. We cannot inspect radiation pattern of radio wave around antenna. Embedding antenna to the final product is even much more challenging. Instead of going down from theoretical basis, we have started with known working reference design and enhance our system over time. In testing and debugging phase, we ignore effects of antenna shape and orientation during calibrating and locating. Technically, all of these effects need to be considered seriously and tested carefully. Even we can adjust the system to make it work better, we cannot understand deeply about electromagnetic characteristics of our products, including tags and detectors.

We claim that the situation will be more complicated if the tracking system is deployed in noisy environments such that in Intel validation labs. Every locating method is sensitive to noise and electromagnetic interference. Our final tests were conducted in a quite clean environment which is not a good mimic of a validation lab. Improving hardware and software of the system might help it more tolerated in real environment. About locating algorithms, we did try with three different algorithms: fingerprinting with Euclidean distance method, neural network, and propagation loss model. There was no time to test all of them; then we decided to test the easy working method.

# 5 Conclusions

We have a complete system that achieves small size, low cost, and battery life that exceeds 1 month. As for accuracy, when a tag is placed on exactly a location that was calibrated, success rates are at least 90%. The average accuracy, or error, over the tested tracking area is about two meters. Basically, we have achieved all requirements given by the sponsor: size, power, and accuracy. In fact, we specified a challenging accuracy which is 1.5m (5 ft.). However, we claim that such accuracy level is difficult to be achieved with limitation of radio technology as well as with prototypes in this capstone project.

There is also the trade-off between the system’s cost and performance. Obviously, tracking TIU in Intel’s validation lab requires high reliability rather than high accuracy since the system must tolerate to noise in lab environment while TIUs are pretty large PCBs that can be easily found within 5m.

Further work to be done includes refining the testability of the system, analyzing antenna radiation pattern, and improving the robustness of the location algorithms. The hardware design could be optimized further to improve the system’s performance and reliability.
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

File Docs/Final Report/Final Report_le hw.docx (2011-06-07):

## 1.1 Hardware

### 1.1.1 Overview

DetectorTagFront-endProxy


The system consists of three main devices: tags, detectors and proxy. Tag is attached to the tracking asset and broadcast its data to detectors. Detectors are on fixed locations, they whether receive data from tag or from another detector. All data will be relayed toward proxy by detectors. For system mobility, proxy is a standalone module that can connects to local wireless LAN and relays data to back-end system. Since the system requires large range of tracking, tags, detectors and proxy are active broadcasting devices and need to be powered from power source.

Front-end system devices use RF technologies for communicating and locating. Data on the front-end system are devices info which are used for device identifications and Received Signal Strength Indication (RSSI) (measured by detector as receiving a broadcast from a tag) used for locating method. The hardware are designed to give reliable signal strength reading as well as data transferring.

### 1.1.2 Component Selections

These are selected carefully to make sure they meet these main requirements: small size, low power consumption and low price. Also, it is important that they are available and well-supported.


RFM12B-S2 Wireless Transceiver Module | WiFly GSX Breakout | ATMega328P – 28 DIP Pinout | ATMega32P – 32 TQFP Pinout

Refer to datasheets provided by manufacturers for more information (See Useful Links section in Appendices).
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

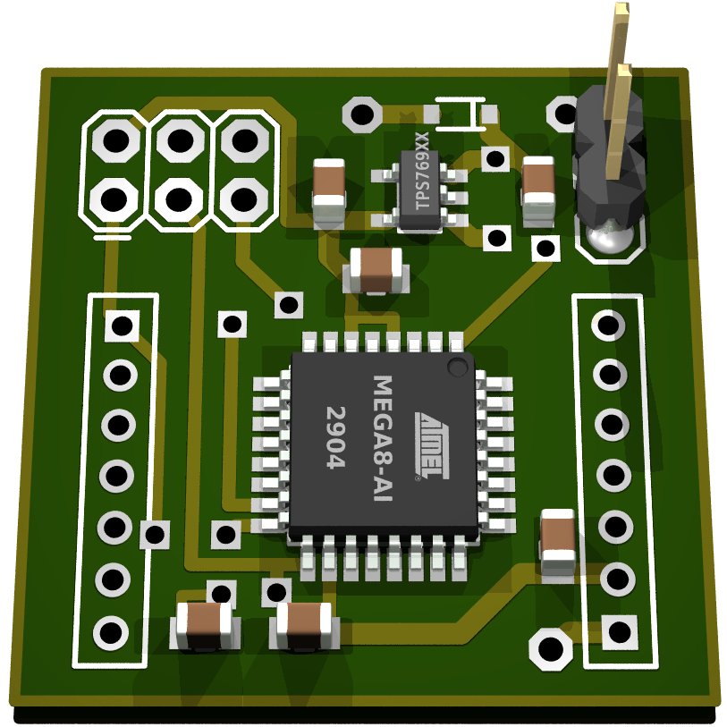
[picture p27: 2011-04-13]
Hardware/Tag/Tag.png

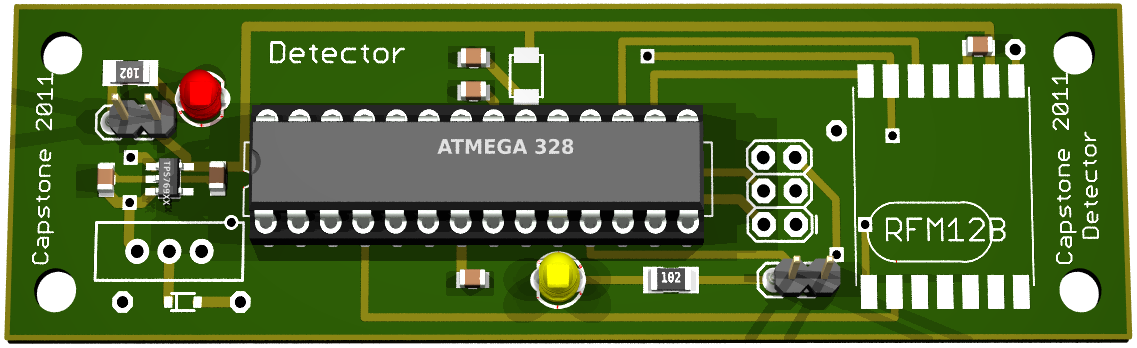
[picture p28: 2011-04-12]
Hardware/Detector/Detector.png

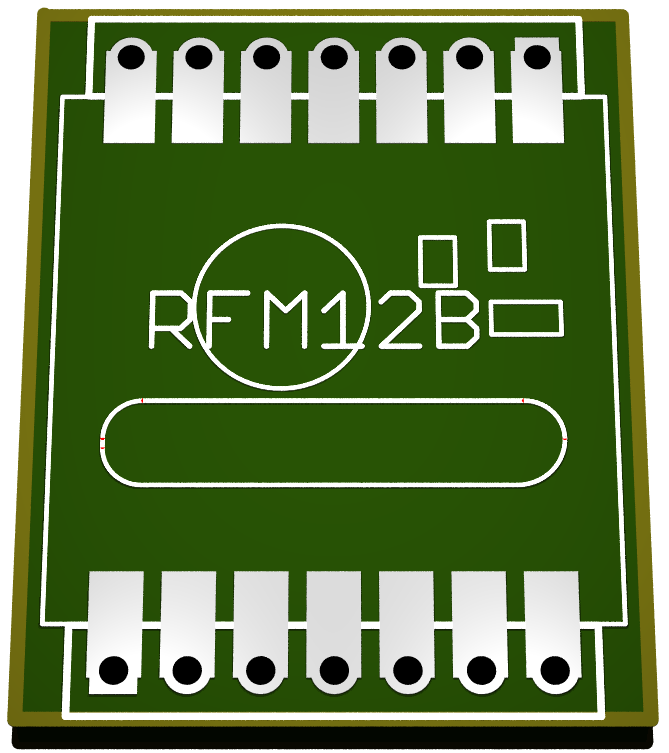
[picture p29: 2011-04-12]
Hardware/Breakout_RFM12B/Breakout_RFM12B.png

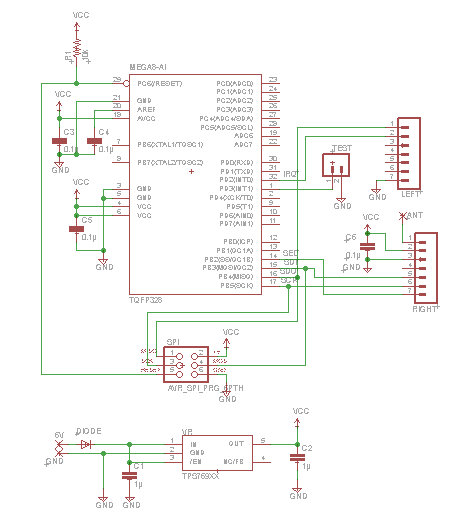
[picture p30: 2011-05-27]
Docs/Images/tag_schem.png

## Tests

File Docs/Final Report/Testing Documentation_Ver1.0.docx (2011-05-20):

Portland State University

Electrical and Computer Engineering Department

11

Capstone 2011

TIU Tracking Project – Testing Documentation

Sponsor: Intel

Advisor: Prof. Robert Daasch

Members: Dung Le

Tri Truong

Lynh Pham

Man Hoang

Daniel Ferguson

## Version History

Version | Primary Author | Revision Date | Approved By | Approval Date | Description of version
1.0 | Tri Truong | 4/18/2011 | | | Outline and test case descriptions

# 1 Introduction

# 2 Reference Documents

## 2.1 Requirements Specification

### 2.1.1 Functional Requirements

The key functionalities of the system are as follows:

- The primary user interface will be a web application
- Locations of TIUs will be displayed on an interactive 2D map within the user interface
- The user interface will show when an asset tag has low battery or when it is out of bounds

### 2.1.2 Non-Functional Requirements

- The system will be able to track any TIU within a 10,000 sq ft area
- A tester in Intel lab occupies roughly 25 sq feet and the system will be able to locate the TIUs with an accuracy of 5 feet
- The locations of tracked TIUs will be updated within 10 minute intervals
- The asset tags must fit within a 1” x 1” x 1” dimension
- The asset tags will be permanently attached to the TIUs during operation
- The asset tags must use their own source of power. If the power source is a battery, then life must exceed one month
- The system will provide a user interface for adding and removing devices
- The system will provide a user interface to configure the geometry of the tracking area
- The locations in the database will be retained for 2 years
- The system will be able to operate properly in temperature range from -25°C to 85°C
- Parts and components will be available for manufacturing and maintaining
- All documentations regarding design, setup, use, and maintenance will be provided
- The system will not infringe upon existing patents, copyrights and trademarks and will comply with FCC rules and regulations

## 2.2 Datasheets

### 2.2.1 Microcontroller ATMega328P

http://www.atmel.com/dyn/resources/prod_documents/8271S.pdf

### 2.2.2 Wireless Transceiver RFM12B-S2

http://www.sparkfun.com/datasheets/Wireless/General/RFM12B.pdf

### 2.2.3 Wi-Fi Transceiver Module WiFly

http://www.sparkfun.com/datasheets/Wireless/WiFi/rn-131-ds.pdf

## 2.3 Industry Standards

# 3 Test Plan

# 4 Test Cases

Test case properties: accurate, economical, limited in complexity, repeatable, appropriate, traceable, self-cleaning

## 4.1 Unit Test

Purpose: A unit test is a complete test of a module’s functionality. In order to be a complete check, a unit test consists of a set of test cases each of which establishes that the module performs a single unit of functionality to some specification.

### 4.1.1 Hardware

#### 4.1.1.1 Power Supply Unit

Test Writer: Lynh Pham
Test Case Name | Power Supply Unit | Test ID #: | Pwr_01
Description: | Measure output voltage of voltage regulator. Input voltage is supplied by power supply in capstone lab. Record output voltage versus input voltage values. | Type: | [x] white box [ ] black box

Tester Information
Name of Tester: | | Lynh Pham | | Date:
Hardware Version: | | Voltage regulator Mic5205 | | Time:
Setup: | | Connect voltage meter to jumper VCC output (JP_PWR) to measure output voltage
Test | Input Voltage | Expected Output | Pass | | Fail | N/A | Comments
1 | Check the red LED | Should be on with the connected jumper
2 | Connect 6V DC (4xAA batteries) to power jack | Output should be 3.3V+3%
3 | Connect 9V DC battery to power jack | Output should be 3.3V+3%
4 | Connect 9V adapter to power jack | Output should be 3.3V+3%
Overall test result:

Tester Information
Name of Tester: | | Lynh Pham | | Date:
Hardware Version: | | Voltage regulator XC6221 | | Time:
Setup: | | Connect voltage meter to jumper VCC output (JP_PWR) to measure output voltage
Test | Input Voltage | Expected Output | Pass | | Fail | N/A | Comments
1 | Check the red LED | Should be on with the connected jumper
2 | Connect 6V DC (4xAA batteries) to power jack | Output should be 3.3V+3%
3 | Connect 6V DC battery to power jack | Output should be 3.3V+3%
Overall test result:

#### 4.1.1.2 Asset Tag

Test Writer: Lynh Pham
Test Case Name | Asset Tag Electrical Testing | Test ID #: | Tag_01
Description: | Checks the asset tag responding RSSI outputs. | Type: | [x] white box [ ] black box

Tester Information
Name of Tester: | | Lynh Pham | | Date:
Hardware Version: | | Asset tag | | Time:
Setup: | | Remove the breakout board then connect the programmer cable to the SPI on the board. Power the testing board. Connect the base station to a PC by USB cable.
Step | Action | Expected result | Pass | | Fail | N/A | Comments
1 | Compile the final firmware version. | Arduino software should generate no warning/error
2 | Download firmware to MCU | AVR Studio should generate no error
3 | Turn off power
4 | Remove the cable from SPI
5 | Insert the breakout board into the tag
6 | Turn on power
7 | Open software controller | A new window should open
8 | Click Start | RSSI signal should be showed up on the window with Tag ID
9 | Repeat step 1-8 for other tags
Overall test result:

#### 4.1.1.3 Detector

Test Writer: Lynh Pham
Test Case Name | Detector Electrical Testing | Test ID #: | Dec_01
Description: | Checks the detector receiving RSSI from the asset tag. | Type: | [x] white box [ ] black box

Tester Information
Name of Tester: | | Lynh Pham | | Date:
Hardware Version: | | Detector | | Time:
Setup: | | Connect the programmer cable to the SPI on the board. Power the testing board and an asset tag. Connect the base station to a PC by USB cable.
Step | Action | Expected result | Pass | | Fail | N/A | Comments
1 | Check the red LED | Should be on when turn the power switch on
2 | Compile the final firmware version. | Arduino software should generate no warning/error
3 | Download firmware to MCU | AVR Studio should generate no error
4 | Turn off power | The red LED should be off
5 | Remove the cable from SPI
6 | Turn on power | The red LED should be on
7 | Open software controller | A new window should open
8 | Check the green LED | Should be blinking with the connected jumper
9 | Click Start | RSSI signal should be showed up on the window with detector ID and Tag ID
10 | Repeat step 1-9 for other detectors
Overall test result:

#### 4.1.1.4 Proxy

Test Writer: Daniel
Test Case Name | Proxy Electrical Testing | Test ID #:
Description: | | Type: | [x] white box [ ] black box

### 4.1.2 Firmware

#### 4.1.2.1 Asset Tag

Test Writer: Dung Le
Test Case Name | Asset Tag Firmware Test | Test ID #:
Description: | Test electrical connection on prototype board of asset tag. LED blinking program is flashed on chip to test if ATMega328P chip work properly. | Type: | [x] white box [ ] black box

#### 4.1.2.2 Detector

Test Writer: Dung Le
Test Case Name | Detector Firmware Test | Test ID #:
Description: | Test electrical connection on prototype board of detector. LED blinking program is flashed on chip to test if ATMega328P chip work properly. | Type: | [x] white box [ ] black box

#### 4.1.2.3 Proxy

Test Writer: Daniel
Test Case Name | Proxy Firmware Test | Test ID #:
Description: | | Type: | [x] white box [ ] black box

### 4.1.3 Software

#### 4.1.3.1 Controller

Test Writer: Daniel
Test Case Name | Asset Tag Test #1 | Test ID #:
Description: | Test basic functions of controller software: support calibrating, location mode, transaction with database. | Type: | [x] white box [ ] black box

#### 4.1.3.2 Location Engines

Test Writer: Tri Truong
Test Case Name | Neural Net implementation Test | Test ID #:
Description: | Test the implementation of Location Engine using neural network concept. Faked data is fed to methods of the Location Engine. | Type: | [x] white box [ ] black box

Test Writer: Man Hoang
Test Case Name | Propagation Loss Model Test | Test ID #:
Description: | Test the implementation of Location Engine using neural network concept. Faked data is fed to methods of the Location Engine. Check error handling when methods are called. | Type: | [x] white box [ ] black box

Test Writer: Dung Le
Test Case Name | Euclidean Distance Method Test | Test ID #:
Description: | Test the implementation of Location Engine using neural network concept. Faked data is fed to methods of the Location Engine. Check error handling when methods are called. | Type: | [x] white box [ ] black box

#### 4.1.3.3 Web-based application

##### 4.1.3.3.1 Server side

Test Writer: Man Hoang
Test Case Name | Server side | Test ID #:
Description: | Test basic functions of server side. Test response of the server to a request sent from client. Return data from server is faked (random). | Type: | [x] white box [ ] black box

##### 4.1.3.3.2 Client side

Test Writer: Man Hoang
Test Case Name | Web-based application – Client side test | Test ID #:
Description: | Test basic functions of client side of the Web-based application as User Interface | Type: | [x] white box [ ] black box

## 4.2 Integration Test

Purpose: Test of two or more modules or hardware/software together. Integration testing checks that the major modules of the overall system operate correctly together

### 4.2.1 Software Integration

Test Writer: Daniel
Test Case Name | Controller – Location Engine Integration | Test ID #:
Description: | Test the integration of location engines and the controller application by calling constructors, methods determined by the common interface. Fake data is created by the controller and fed to location engines. Check to returned result of location engines. | Type: | [x] white box [ ] black box

Test Writer: Man Hoang
Test Case Name | Server-Client Integration test | Test ID #:
Description: | Test transaction between the server and client. Transacted data which is created by server is faked. The return location from server is used by client side to display the location of requested asset tag. | Type: | [x] white box [ ] black box

### 4.2.2 Hardware Integration

Test Writer: Daniel
Test Case Name | Detector – Asset Tag Communication | Test ID #:
Description: | Test transmitting and receiving between a detector and an asset tag. The data packet with specified fields is checked. Detector is implemented on Arduino board. Serial Monitor is used to record the received data packet. Packet’s fields are check to ensure data integrity. | Type: | [x] white box [ ] black box

### 4.2.3 Hardware-Software Integration

Test Writer: Daniel
Test Case Name | Calibrating Mode Test | Test ID #:
Description: | Test hardware-software integration in calibrating mode. Data flow is checked: data packet from asset tags through detectors to proxy, and then recorded by controller to database and calibrating data file. | Type: | [x] white box [ ] black box

Test Writer: Daniel
Test Case Name | Locating Mode Test | Test ID #:
Description: | Test hardware-software integration in calibrating mode. Data flow is checked: data packet from asset tags through detectors to proxy, and then recorded by controller. Locating data will be passed to location engine and location engine in turn return location of asset tags. Correctness of locations is not a concern in this test. | Type: | [x] white box [ ] black box

## 4.3 Acceptance Test

Purpose: An acceptance test is a formal document stipulating the conditions under which the customer will accept the system.

Test Writer: Man Hoang
Test Case Name | Tracking System Test #1 | Test ID #:
Description: | Test the performance of the locating system: The system must return the current location of a requested asset tag with accuracy within 1.5m, including battery level of the asset tag. Information is displayed on a web-based application. | Type: | [x] white box [ ] black box

Test Writer: Lynh Pham
Test Case Name | Battery Life of Asset Tag | Test ID #:
Description: | Measure the battery life of asset tags in normal operation mode. The battery of asset tags must last at least one month as requires. The stress test is used to evaluate battery life and conducted in shorter interval of time (2 days) than reality. | Type: | [x] white box [ ] black box

Test Writer: Tri Truong
Test Case Name | System Deployment Time | Test ID #:
Description: | Measure deployment time of the complete system, including | Type: | [x] white box [ ] black box

Test Writer: Daniel
Test Case Name | User configuration – Controller Module Test | Test ID #:
Description: | Test usability of the step-by-step guide for the front-end software modules. Follow Software User Guide instructions to make sure the user guide is well-explained. | Type: | [x] white box [ ] black box

Test Writer: Tri Truong
Test Case Name | Detector Installation Test | Test ID #:
Description: | Test deployed detectors which are mounted on wall/ceiling to ensure reliability, safety, and detectable range of detectors. Measure force required to detach detector out of wall/ceiling. | Type: | [x] white box [ ] black box

## 4.4 Parametric Test

Purpose: testing to determine or confirm detailed parameters of a completed design. The design must satisfy three figures of merit: accuracy, dimension of asset tags, and battery life of asset tag. Parameters of other modules should be also tested before delivering to our customers (Intel Sponsors).

Test Writer: Tri Truong
Test Case Name | RF Transceiver Detectable Range Test | Test ID #:
Description: | Test the detectable range of the locating system with various settings of broadcasting power of asset tags (from 0 dB to -20 dB). | Type: | [x] white box [ ] black box

Test Writer: Tri Truong
Test Case Name | Tracking System Cover Range Test | Test ID #:
Description: | Measure the range of tracking system in which an asset tag can be located. Conduct test to make sure any asset tag can be located in the setup area. | Type: | [x] white box [ ] black box

### 4.4.1 Device Dimension

#### 4.4.1.1 Asset Tag

Test Writer: Lynh Pham
Test Case Name | Detector Dimension Measurement | Test ID #:
Description: | Measure size of all detectors. The size of detectors was not specified as a design goal. Dimension of detectors is reported as a part of deliverables. | Type: | [x] white box [ ] black box

#### 4.4.1.2 Detector

Test Writer: Lynh Pham
Test Case Name | Detector Physical Dimension | Test ID #:
Description: | Test the asset tags’ size to ensure it satisfies the requirements. The asset tags must fit into 1 x 1 x 1 cubic in. Measurement is conducted with 10 asset tags. | Type: | [x] white box [ ] black box

#### 4.4.1.3 Proxy

### 4.4.2 Accuracy of Locating Results

### 4.4.3 Precision of Location Results

### 4.4.4 Response time of Web-based Application

### 4.4.5 Power Consumption

#### 4.4.5.1 Asset Tag

Test Writer: Dung Le
Test Case Name | Power consumption of Asset tag | Test ID #:
Description: | Measure current drawn by an asset tag in the operating mode (broadcasting signal), idle (stand by) mode, and sleep mode. | Type: | [x] white box [ ] black box

#### 4.4.5.2 Detector

Test Writer: Dung Le
Test Case Name | Power consumption of Asset tag | Test ID #:
Description: | Measure current drawn by an asset tag in the operating mode (broadcasting signal), idle (stand by) mode, and sleep mode. | Type: | [x] white box [ ] black box

#### 4.4.5.3 Proxy

Test Writer: Daniel
Test Case Name | Power consumption of Proxy Module | Test ID #:
Description: | Measure current drawn by an asset tag in the operating mode (broadcasting signal), idle (stand by) mode, and sleep mode. | Type: | [x] white box [ ] black box

### 4.4.6 Battery Life

#### 4.4.6.1 Asset Tag

#### 4.4.6.2 Detector

### 4.4.7 Detectable Range

## 4.5 Functional Test

Functional tests are conducted to demonstrate that the delivered tracking system satisfies requirements of the capstone project. Test cases are built based on requirements specification.

Test Writer: Man Hoang
Test Case Name | Asset tag request Test | Test ID #:
Description: | Test response of the web-based application to random requests of users. The last known location of the request asset tags is displayed on 2D map. | Type: | [x] white box [ ] black box

Test Writer: Tri Truong
Test Case Name | Low Battery/Out of bound Alert Test | Test ID #:
Description: | Test response of the web-based application in the case a requested asset tag has low battery or cannot be detected due to out of range. Alert message is displayed on Web-app. The battery level is displayed to indicate batter’s status. | Type: | [x] white box [ ] black box

# 5 Appendices

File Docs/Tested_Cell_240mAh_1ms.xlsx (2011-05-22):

Time (minutes) | Voltage of battery (V) | Voltage output of VR (V) | Notes
0 | 6.52 |  | Without load
0 | 5.89 | 3.32 | With load
5 | 5.04 | 3.32 | With load
10 | 4.77 | 3.32 | With load
15 | 4.5 | 3.32 | With load
20 | 4.19 | 3.32 | With load
25 | 3.75 | 3.31 | With load
30 | 3.37 | 3.31 | With load
35 | 3.24 | 3.21 | With load
40 | 2.94 | 2.9 | With load
42 | 2.7 | 2.68 | With load
52 | 5.74 |  | Without load
Transmit signal every 1ms with interval 4ms
Number of pulses = 42mins/4ms = 63,000

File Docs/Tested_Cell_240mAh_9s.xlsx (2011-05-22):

Test coin cell battery
Capacity: 240mAh
Broadcast every 9s
Time (Days) | Volatge (V)
0 | 6.49
1 | 5.87
2 | 5.84
3 | 5.83
4 | 5.83
5 | 5.83
6 | 5.83
7 | 5.83
8 | 5.83
9 | 5.83
10 | 5.83
11 | 5.83
12 | 5.83
13 | 5.83
14 | 5.83
15 | 5.83
16 | 5.83
17 | 5.83
18 | 5.83
19 | 5.83
20 | 5.83
21 | 5.83
22 | 5.83
23 | 5.83
24 | 5.82
25 | 5.82
26 | 5.82
27 | 5.82
28 | 5.82
29 | 5.82
30 | 5.82
31 | 5.82

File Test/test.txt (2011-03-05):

testing 1 2 3
Cows are ugly, My dog is beautiful.
I wanna update too!

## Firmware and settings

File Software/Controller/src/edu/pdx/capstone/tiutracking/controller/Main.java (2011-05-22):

/* Controller
 * This application fills the role as mediator between 
 * the Proxy, LocationEngine, and Database.
 * 
 * Key Aspects:
 * 	Three modes of operation
 * 		1) Collect; Saves data coming from proxy into a csv file
 * 		2) Calibrate; Saves data coming from proxy into Database.
 * 		3) Locate; Provides previously collected calibration data to location engines.
 * 			Formats data coming from proxy into a format suitable for a Location Engine to
 * 			calculate a location.
 * 
 * Architecture:
 * 	The GUI has 3 buttons; Collect, Calibrate, and Locate. Each has their own event handler.
 * 	There are 3 runnable thread objects; CollectReader, CalibrateReader, and LocateReader. They are responsible for
 *  reading data from a Port, and providing the functionality that is associated with each mode of operation. Each of the 3 buttons starts their 
 *  respective Reader. Each Reader inherits from the PortReader class. The PortReader class provides base 
 *  functionality for reading and parsing incoming data from a proxy.
 *  
 *  CalibrateReader, and LocateReader access a Database.
 * 
 *  Authors: Daniel Ferguson,
 *  Version: 0.9
 */

package edu.pdx.capstone.tiutracking.controller;
import edu.pdx.capstone.tiutracking.common.*;

import edu.pdx.capstone.tiutracking.gammaengine.BetaEngine;
import edu.pdx.capstone.tiutracking.gammaengine.GammaEngine;
import edu.pdx.capstone.tiutracking.kengine.KEngine;
//import edu.pdx.capstone.tiutracking.locator.FingerPrint;

import java.awt.EventQueue;
import java.awt.Font;

import javax.swing.JFrame;
import javax.swing.JTextField;
import javax.swing.JButton;
import java.awt.event.ActionListener;
import java.awt.event.ActionEvent;

import gnu.io.*;

import java.awt.event.WindowAdapter;
import java.awt.event.WindowEvent;
import java.text.DateFormat;
import java.text.SimpleDateFormat;
import java.util.*;
import java.util.Date;
import java.util.concurrent.ConcurrentLinkedQueue;

import javax.swing.JComboBox;
import java.awt.event.ComponentAdapter;
import java.awt.event.ComponentEvent;
import java.io.File;
import java.io.FileWriter;
import java.io.IOException;
import java.io.InputStream;
import java.io.OutputStream;
import java.net.InetSocketAddress;
import java.net.Socket;
import java.net.UnknownHostException;

import javax.swing.ButtonGroup;
import javax.swing.JOptionPane;
import javax.swing.JTextArea;
import javax.swing.JScrollPane;
import javax.swing.JLabel;
import javax.swing.JMenuBar;
import javax.swing.JMenu;
import javax.swing.JRadioButtonMenuItem;
import javax.swing.JPanel;
import java.awt.Color;
import javax.swing.border.TitledBorder;
import javax.swing.table.TableColumn;
import javax.swing.table.TableModel;
import javax.swing.UIManager;

import java.sql.*;

import javax.swing.JTabbedPane;
import javax.swing.JMenuItem;
import javax.swing.JTable;
import javax.swing.JRadioButton;
import javax.swing.event.ChangeListener;
import javax.swing.event.ChangeEvent;
import javax.swing.JCheckBox;

public class Main {

	private enum AppViewMode{
		CALIBRATION,
		COLLECTION,
		LOCATING
	}
	
	private enum LocatorChoices{
		FINGERPRINT,
		BETA,
		KEWTON
	}
	
	private ConcurrentLinkedQueue<String> generalDisplayMessages=null;
	private LocatorChoices locatorChoice=LocatorChoices.KEWTON;
	private LocationEngine locator;
	private AppViewMode appViewMode;
	private JFrame frmController;
	private JComboBox cbxCOMPorts;
	private JTextArea txtOutput;
	
	private CommPort commPort;
	private SerialPort serialPort;
	private Socket socketPort;
	
	Thread writerThread;
	Thread readerThread;
	LocatorReader locatorReader;
	CollectorReader collectorReader;
	CalibratorReader calibratorReader;
	Writer writer;
	private JTextField txtLocationDescription;
	private JLabel lblPreviousLocationDescription;
	private ToggleButton btnStartCalibrating;
	private ToggleButton btnStartCollecting;
	private ToggleButton btnStartLocating;
	private JTextField txtCalibrateX;
	private JTextField txtCalibrateY;
	private JTextField txtCalibrateTagID;
	private JTextField txtCalibrateBlockNumber;
	private JLabel lblNewLabel;
	private JLabel lblNewLabel_1;
	private JLabel lblNewLabel_2;
	private JLabel lblNewLabel_3;
	private JTabbedPane tabbedPaneMain;
	private JMenu mnFile;
	private JMenuItem mntmExit;
	private JTable tblLocatorConfiguration;
	private JScrollPane scrollPane;
	private JTextField txtModifyTagId;
	private JTextField txtModifyBlockId;
	private JTextField txtModifyDetectorId;
	private JTextField txtModifyRSSIIndex;
	private JTextField txtTimeout;
	private JTextField txtMinimumDetectors;
	private JTextField txtModifyNewValue;
	private JLabel lblNewValue;
	private JScrollPane scrollPane_1;
	private JTextField txtProxyIPAddress;
	private JTextField txtProxyPort;
	private final ButtonGroup buttonGroup = new ButtonGroup();
	JRadioButton rdbtnSerial;
	JRadioButton rdbtnTcpip;
	private JTextField txtActualX;
	private JTextField txtActualY;
	private JTextField txtMinimumSamplesPerCalDet;
	private JTextField txtRSSIThreshold;
	private JTextField txtCalibrateMinDetectors;
	private JLabel lblMinimumDetectorParticipants;
	private JTextField txtListLenThreshold;
	private JLabel lblDetectorExclusionList;
	/**
	 * Launch the application.
	 */
	public static void main(String[] args) {
		EventQueue.invokeLater(new Runnable() {
			public void run() {
				try {
					Main window = new Main();
					window.frmController.setVisible(true);
				} catch (Exception e) {
					e.printStackTrace();
				}
			}
		});
	}

	public static LocationEngine createLocator(LocatorChoices locatorChoice) {
		switch (locatorChoice){
		case FINGERPRINT:
			return (LocationEngine)new FingerPrint();
		case BETA:
			return(LocationEngine)new BetaEngine();
		case KEWTON:
			return(LocationEngine)new KEngine();
		}
		return null;
	}
	public static void populateConfigurationTable(LocationEngine locator, JTable tblLocatorConfiguration) {
		ArrayList<ConfigurationParam> parameters = locator.getConfiguration();
		if (parameters != null){
			ConfigurationTableModel ctm = new ConfigurationTableModel();
			ctm.setData(parameters);
			tblLocatorConfiguration.setModel(ctm);
			tblLocatorConfiguration.setFont(new Font(null,Font.PLAIN, 8));
			tblLocatorConfiguration.setAutoResizeMode(JTable.AUTO_RESIZE_SUBSEQUENT_COLUMNS);   
			tblLocatorConfiguration.getColumnModel().getColumn(0).setPreferredWidth(55);
			tblLocatorConfiguration.getColumnModel().getColumn(1).setPreferredWidth(400);					
			tblLocatorConfiguration.getColumnModel().getColumn(2).setPreferredWidth(55);
		}else{
			for (int i = 0;i < tblLocatorConfiguration.getColumnModel().getColumnCount();i++){
				tblLocatorConfiguration.getColumnModel().removeColumn(tblLocatorConfiguration.getColumnModel().getColumn(0));
			}
		}
	}
	public boolean openPort() throws NoSuchPortException,
	PortInUseException, UnsupportedCommOperationException, UnknownHostException, IOException {
		
		if (rdbtnSerial.isSelected()){
			if (cbxCOMPorts.getItemCount() < 1 || cbxCOMPorts.getSelectedIndex() == -1){
				JOptionPane.showMessageDialog(null,"A port was no selected. Please select a port.");
				return false;
			}
			String selectedPortName = cbxCOMPorts.getItemAt(cbxCOMPorts.getSelectedIndex()).toString();
			CommPortIdentifier port = CommPortIdentifier.getPortIdentifier(selectedPortName);
			commPort = port.open("Controller",2000);
			if (!(commPort instanceof SerialPort)){
				JOptionPane.showMessageDialog(null,"Only Serial Ports are supported. Please select another port.");
				return false;
			}
			serialPort = (SerialPort) commPort;
			serialPort.setSerialPortParams(19200, 
										   SerialPort.DATABITS_8, 
										   SerialPort.STOPBITS_1, 
										   SerialPort.PARITY_NONE);
		}else if (rdbtnTcpip.isSelected()){
			socketPort = new Socket();//txtProxyIPAddress.getText(), Integer.parseInt(txtProxyPort.getText()));
			socketPort.setReuseAddress(true);
			socketPort.connect(new InetSocketAddress(txtProxyIPAddress.getText(), Integer.parseInt(txtProxyPort.getText())), 1000);
			
		}
		return true;
	}
	
	/*loadCalibrationData
	 * 	deserializes an ArrayList<DataPacket> from the local filesystem
	 * 	and returns it on success. returns null if there does not exist
	 * 	previously serialized calibration data.
	 */
	@SuppressWarnings("unchecked")
	private ArrayList<DataPacket> loadCalibrationData()
			throws ClassNotFoundException, SQLException, IOException {
		File calFile = new File("calibrationdata.dat");
		if (!calFile.exists()){
			//System.out.println("Calibration data not found.");
			printDisplayMessage("Calibration data not found\n");
			return null;
		}									
		return (ArrayList<DataPacket>)ObjectFiler.load("calibrationdata.dat");
	}
	
	@SuppressWarnings("unchecked")
	private void storeCalibrationData(int tagId, int blockId, DataPacket dataPacket)
			throws ClassNotFoundException, SQLException, IOException {
		//TODO: make cal data directory and data file configurable.	
		
		/*for (Map.Entry<Integer,ArrayList<Integer>> e: dataPacket.rssiTable.entrySet()){
			double stdev = Statistics.stdDev(e.getValue());
			System.out.println(String.format("Calibration Data: StdDev for Detector %1$d: %2$f",e.getKey(),stdev));
			int median = Statistics.median(e.getValue());
			ArrayList<Integer> values = new ArrayList<Integer>();
			if (values.size() >= 5){
				for (int i = 0;i < e.getValue().size();i++){
					int value = e.getValue().get(i);
					if (value <  (median-stdev) || value > (median+stdev)){
						//This must be an outlier; remove it.					
						System.out.println(String.format("CalibrationData: Removing outlier %1$d from Detector's %2$d set",value,e.getKey()));					
					}else{					
						values.add(value);
					}
				}			
				dataPacket.rssiTable.put(e.getKey(), values);
			}else{
				System.out.println("Not enough calibration data for detector "+e.getKey()+" to filter.");				
			}
			
		}*/
		
		
		
		ArrayList<DataPacket> calibrationData=null;			
		File calFile = new File("calibrationdata.dat");
		if (calFile.exists()){				
			calibrationData = (ArrayList<DataPacket>)ObjectFiler.load("calibrationdata.dat");
		}else{
			calibrationData = new ArrayList<DataPacket>();
		}
		
		//If it exists, replace entry with a matching block Id, else just append it.
		boolean foundExisting=false;		
		for (int h = 0;h < calibrationData.size();h++){
			if (calibrationData.get(h).blockId == blockId && calibrationData.get(h).tagId == tagId){
				calibrationData.set(h, dataPacket);
				foundExisting = true;
				break;
			}
		}
		if (!foundExisting){
			calibrationData.add(dataPacket);
		}
		//Serialize Calibration Data..
		ObjectFiler.save("calibrationdata.dat", calibrationData);
	}
	
	public void printDisplayMessage(String message){
		txtOutput.append(message);
		txtOutput.setCaretPosition(txtOutput.getDocument().getLength());
	}
	/**
	 * Create the application.
	 */
	public Main() {
		//GUI init
		initialize();

		//member variable init
		appViewMode = AppViewMode.LOCATING;
		
		//Populate combo box with available serial ports.
		@SuppressWarnings("unchecked")
		Enumeration<CommPortIdentifier> ports = CommPortIdentifier.getPortIdentifiers();
		while (ports.hasMoreElements()){
			CommPortIdentifier port = ports.nextElement();	
			cbxCOMPorts.addItem(port.getName());
		}	
	}
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

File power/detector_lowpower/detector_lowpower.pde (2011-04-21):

/*****************************************************************
 * Detector Low power consumption code                           *
 * by Dung Dang Le, Daniel Ferguson,                             *
 * This code is licensed under GPL v.2                           *
 *                                                               *
 * reference source:                                             *
 * http://www.arduino.cc/playground/Learning/ArduinoSleepCode    *
 * 2006 MacSimski 2006-12-30                                     *
 * 2007 D. Cuartielles 2007-07-08 - Mexico DF                    * 
 *                                                               *
 * Detector saves its battery power by:                          *
 
 * 
 *****************************************************************
 * Set up:                                                       *
 * RFM12B (REVISION B) ->  ATMEGA328                             *
 *              SDI    ->  MOSI (PB3)                            *
 *              SDO    ->  MISO (PB4)                            *
 *              SCK    ->  SCK  (PB5)                            *
 *              nSel   ->  SS   (PB2)                            *
 *              IRQ    ->  INT0 (PD2)                            *
 * ARSSI (at resistor) ->  PC0  (analog input 0)                 *
 *              VCC    ->  AVCC                                  *
 *****************************************************************/
 /* Reference notes:
  * what will make pin2 go LOW activating INT0 external interrupt, bringing
  * the MCU back to life
  * NOTE: when coming back from POWER-DOWN mode, it takes a bit
  *       until the system is functional at 100%!! (typically <1sec)
  * DDLE: WILL BE TESTED 
  *
  * functions provided in avr/power.h to disable other hardware modules:
  * power_adc_disable(),power_spi_disable(),power_timer0_disable(), 
  * power_timer1_disable(),power_timer2_disable(),power_twi_disable() power_usart0_disable
  */

 
#include <RF12.h>
#include <Ports.h>
#include <avr/sleep.h>
#include <avr/power.h>
//************************************************************
// Detector properties
#define FROM_TAG 		0
#define PAYLOAD_SIZE 	        6
#define MyID			2

#define FASTADC 1

// defines for setting and clearing register bits
#ifndef cbi
#define cbi(sfr, bit) (_SFR_BYTE(sfr) &= ~_BV(bit))
#endif
#ifndef sbi
#define sbi(sfr, bit) (_SFR_BYTE(sfr) |= _BV(bit))
#endif

unsigned char payload[PAYLOAD_SIZE+1];
int tagMessageReceived=0;
int detMessageReceived=0;

//*****************************************************************
// sleep variables and functions
int wakePin = 2;                 // pin used for waking up
int sleepStatus = 0;             // variable to store a request for sleep
//int count = 0;                   // counter

void power_down()         
{
    /* Now is the time to set the sleep mode. In the Atmega8 datasheet
     * http://www.atmel.com/dyn/resources/prod_documents/doc2486.pdf on page 35
     * there is a list of sleep modes which explains which clocks and 
     * wake up sources are available in which sleep mode.
     *
     * In the avr/sleep.h file, the call names of these sleep modes are to be found:
     *
     * The 5 different modes are:
     *     SLEEP_MODE_IDLE         -the least power savings 
     *     SLEEP_MODE_ADC
     *     SLEEP_MODE_PWR_SAVE
     *     SLEEP_MODE_STANDBY
     *     SLEEP_MODE_PWR_DOWN     -the most power savings
     *
     * For now, we want as much power savings as possible, so we 
     * choose the according 
     * sleep mode: SLEEP_MODE_PWR_DOWN
     * 
     */  
     
    set_sleep_mode(SLEEP_MODE_IDLE);   // sleep mode is set here

    sleep_enable();          // enables the sleep bit in the mcucr register
                             // so sleep is possible. just a safety pin 

    /* Now it is time to enable an interrupt. We do it here so an 
     * accidentally pushed interrupt button doesn't interrupt 
     * our running program. 
     */
    
    power_adc_disable();
    //power_spi_disable();
    //power_timer0_disable();
    power_timer1_disable();
    power_timer2_disable();
    power_twi_disable() ;
    power_usart0_disable();
    
    sleep_mode();            // here the device is actually put to sleep!!
                             // THE PROGRAM CONTINUES FROM HERE AFTER WAKING UP

    power_adc_enable();
    //power_spi_enable();
   // power_timer0_enable();
    power_timer1_enable();
    power_timer2_enable();
    power_twi_enable() ;
    power_usart0_enable();


    sleep_disable();         // first thing after waking from sleep:
                             // disable sleep...
   // detachInterrupt(0);    // disables interrupt 0 on pin 2 so the 
                             // wakeUpNow code will not be executed 
                             // during normal running time.
                        
}

void sleepNow()         
{
    /* Now is the time to set the sleep mode. In the Atmega8 datasheet
     * http://www.atmel.com/dyn/resources/prod_documents/doc2486.pdf on page 35
     * there is a list of sleep modes which explains which clocks and 
     * wake up sources are available in which sleep mode.
     *
     * In the avr/sleep.h file, the call names of these sleep modes are to be found:
     *
     * The 5 different modes are:
     *     SLEEP_MODE_IDLE         -the least power savings 
     *     SLEEP_MODE_ADC
     *     SLEEP_MODE_PWR_SAVE
     *     SLEEP_MODE_STANDBY
     *     SLEEP_MODE_PWR_DOWN     -the most power savings
     *
     * For now, we want as much power savings as possible, so we 
     * choose the according 
     * sleep mode: SLEEP_MODE_PWR_DOWN
     * 
     */  
     
    set_sleep_mode(SLEEP_MODE_IDLE);   // sleep mode is set here

    sleep_enable();          // enables the sleep bit in the mcucr register
                             // so sleep is possible. just a safety pin 

    /* Now it is time to enable an interrupt. We do it here so an 
     * accidentally pushed interrupt button doesn't interrupt 
     * our running program. 
     */
    
    sleep_mode();            // here the device is actually put to sleep!!
                             // THE PROGRAM CONTINUES FROM HERE AFTER WAKING UP

    sleep_disable();         // first thing after waking from sleep:
                             // disable sleep...
   // detachInterrupt(0);    // disables interrupt 0 on pin 2 so the 
                             // wakeUpNow code will not be executed 
                             // during normal running time.
                        
}
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

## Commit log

2011-01-31 power management pics from datasheet
2011-02-05 fuse setting
2011-03-05 Mesh - Tag - updated message format, added checksum generation. Mesh - Detector - updated message format, added checksum generation. Also moved base functionality into detector. Mesh - RF12.cpp - mod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
2011-03-17 Detector/Base - added some rf12 style crc check. added code to change the ADC prescaler to 16 instead of default.
2011-03-19 tag with shorter message format
    [tag.pde]
2011-03-24 demo locator engine, using Fingerprint method code written in python
2011-04-01 java implementation of FingerPrint locator
2011-04-02 FIngerPrintLocator first test passed with fake data
2011-04-03 Added battery field to Tag class.
2011-04-03 Added battery initialization in the constructor.
2011-04-04 FingerPrintLocator - initial commit
2011-04-04 FingerPrintLocator - added correct java directory structure
2011-04-04 FingerPrintLocator - removed incorrect source, added correct source
2011-04-04 Controller - integrated FingerPrintLocator into eclipse project
2011-04-04 FingerPrintLocator - changed over to DataPacket. changed over to StatisticValue.
2011-04-04 Firmware - initial commit of base, tag, detector, and arduinolibs
2011-04-04 Controller - fixed a bug. integrated FingerPrint using old school interfaces. tested.
    [Main.java]
2011-04-05 Software - initial commit. Commmon, Controller, and FingerPrint are their own separate projects. Controller references jars.
2011-04-07 Controller - modified the storeCalibrationData function to overwrite calibration data that has the same blockId as the newly collected calibration data. added many comments.
2011-04-07 FingerPrint - added some clarifying intermediate lines of code when calculating euclidean distance for debugging purposes. modified the way the calculated location was assigned to output.
2011-04-09 Controller - currently as GammaEngine integrated. Added some rudimentary support for locator configuration. Changed GUI around to accomodate wider tab control. fixed a mysql bug regarding inserting a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
    [Main.java]
2011-04-11 FingerPrint - moved the logic that existed within the constructor, to the learn method. although incomplete, removed the ability to pass in a statisticMode since it is not part of the standard interf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
2011-04-11 Controller - added radio buttons to select currently active LocationEngine implementation. cleaned some places up, cluttered others. not tested. Added a ToggleButton class
2011-04-15 RF12.cpp - added all the variations for changing the transmit power. These are comments; so select the output power you want, and uncomment it. -9dB is the default.
2011-04-20 Power management - testing version of tag firmware with sleep mode ( radio and MCU ) + watchdog interrupt
2011-04-20 Power management - testing detector firmware with sleep mode (MCU), interrupt generated by radio
2011-04-21 Power management - testing detector firmware with power down mode (MCU), interrupt generated by radio
2011-05-05 Controller - added support for TCP/IP. Changed the readPort, and parseRawSample functions to support two byte RSSI, and detector battery.
2011-05-05 all firmware - added an extra byte foro RSSI, and an extra byte that is reserved for detector battery. completed implementation of battery threshold
2011-05-05 tag_lowpower - added an extra byte for RSSI, and an extra byte that is reserved for detector battery. completed implementation of battery threshold
2011-05-05 rf12 library - finished rf12_lowBat. set battery threshold to a usable value (it is different for detectors than it is for tags)
2011-05-07 Controller - fixed a bug regarding the $ delimiter
    [Main.java]
2011-05-08 FingerPrint locator version 2:added (n-1) model, aliasing inspection, interpolating blocks.
2011-05-13 version 2.1 - added 2 state input filter
2011-05-13 Detector - added a caching mechanism to avoid relaying a message from another detector more than once.
    [detector.pde]
2011-05-13 Base/Proxy - added a mechanism to avoid relaying(sending to controller) a message from a detector more than once.
    [base.pde]
2011-05-14 Controller - added a filter to the calibration data. remove's outliers.
2011-05-15 added simple averaging output filter
2011-05-15 added simple averaging output filter, revised
2011-05-15 Controller - changed the whole timeout scheme. Much much better. Hooked up the timeout and detector participation settings.
    TODO: remove FingerPrint from being embedded into the controller project.
2011-05-15 averaged output filter, revised 2
2011-05-22 Controller - added RSSI Threshold, and max rssi sample
2011-05-22 Detector - added an improved cache idiom. commented out relay capability.
2011-05-22 Base - added improved cache mechanism, for when relays are used. may need to be commented out when not using relays
2011-05-22 with power level
